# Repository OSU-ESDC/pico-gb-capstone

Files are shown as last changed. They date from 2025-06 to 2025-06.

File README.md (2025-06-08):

# Gaming System - A Modified RP2040 GB for the ENGR 512 Capstone group at Oregon State University

This is a fork of the [RP2040-GB Game Boy (DMG) emulator by YouMakeTech, originally forked from Deltabeard's version](https://github.com/YouMakeTech/Pico-GB). RP2040-GB is a Game Boy (DMG) emulator Peanut-GB on the Raspberry Pi RP2040 microcontroller, using an ILI9225 screen. Runs at more than 70 fps without audio emulation. With frame skip and interlacing, can run at up to 120 fps.

This fork includes changes done by me for my Capstone project in Winter/Spring 2025:
* Volume control via rotary encoder support
* Game movement via analog joystick support
* I2C communication with ADC support, enabling the analog joystick to be used

The Gaming System has a 3D printed shell, designed by Justin Gonzalez. You can find the stl files for the print in the print folder. 

# Videos
* [Analog Joystick Functionality](https://www.youtube.com/shorts/wKSmv8ernYQ)
* [Case Dissasembly](https://www.youtube.com/shorts/b-UEHgNEkO8)
* [Volume Knob Functionality](https://www.youtube.com/shorts/HMfL2WKNLts)

# Hardware
## What you need
* (1x) [Raspberry Pi Pico](https://amzn.to/3rAcmDy)
* (1x) [ADS7830 8-bit, 8-channel, I2C ADC](https://www.adafruit.com/product/5836)
* (1x) [Rotary Encoder](https://eecs.engineering.oregonstate.edu/education/tekbotSuite/tekbot/pages/publicInventoryPart.php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)
* (1x) [Analog Joystick](https://eecs.engineering.oregonstate.edu/education/tekbotSuite/tekbot/pages/publicInventoryPart.php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)
* (1x) [2.2inch ILI9225 176×220 LCD Display Module](https://amzn.to/3aNAMD7)
* (1x) [FAT 32 formatted Micro SD card + adapter](https://amzn.to/3ICKzcm) with roms you legally own. Roms must have the .gb extension and must be copied to the root folder.
* (1x) [MAX98357A amplifier](https://www.youmaketech.com/max98357)
* (1x) [2W 8ohms speaker](https://amzn.to/3ikDy6S)
* (8x) [Micro Push Button Switch, Momentary Tactile Tact Touch, 6x6x6 mm, 4 pins](https://amzn.to/3dyXBsx)
* (1x) [Solderable Breadboard](https://amzn.to/3lwvfDi)
* [Dupont Wires Assorted Kit (Male to Female + Male to Male + Female to Female)](https://amzn.to/3HtbvdO)
* [Preformed Breadboard Jumper Wires](https://amzn.to/3rxwVjM)

## Setting up the hardware
#### Most of the setup is here, minus the analog joystick/rotary encoder:
[Pico-GB assembly instructions, circuit diagrams, 3d printed files etc.](https://www.youmaketech.com/pico-gb-gameboy-emulator-handheld-for-raspberry-pi-pico/)
You can find the rest of the setup in the documentation in the /docs folder.  

# Pinout
* I2C SDA = GP0
* I2C SCL = GP1
* UP = GP2
* DOWN = GP3
* LEFT = GP4
* RIGHT = GP5
* BUTTON A = GP6
* BUTTON B = GP7
* SELECT = GP8
* START = GP9
* VOLUME DT = GP10
* VOLUME CLK = GP11
* SD MISO = GP12
* SD CS = GP13
* SD CSK = GP14
* SD MOSI = GP15
* VOLUME MUTE = GP16
* LCD CS = GP17
* LCD CLK = GP18
* LCD SDI = GP19
* LCD RS = GP20
* LCD RST = GP21
* LCD LED = GP22
* MAX98357A DIN = GP26
* MAX98357A BCLK = GP27
* MAX98357A LRC = GP28

# Flashing the firmware
* Download RP2040_GB.uf2 from the [releases page](https://github.com/osu-esdc/pico-gb-capstone/releases)
* Push and hold the BOOTSEL button on the Pico, then connect to your computer using a micro USB cable. Release BOOTSEL once the drive RPI-RP2 appears on your computer.
* Drag and drop the UF2 file on to the RPI-RP2 drive. The Raspberry Pi Pico will reboot and will now run the emulator.

# Preparing the SD card
The SD card is used to store game roms and save game progress. For this project, you will need a FAT 32 formatted Micro SD card with roms you legally own. Roms must have the .gb extension.

* Insert your SD card in a Windows computer and format it as FAT 32
* Copy your .gb files to the SD card root folder (subfolders are not supported at this time)
* Insert the SD card into the ILI9225 SD card slot using a Micro SD adapter

# Building from source
The [Raspberry Pi Pico SDK](https://github.com/raspberrypi/pico-sdk) is required to build this project. 
To start, clone the SDK in a known folder (labeled as path-to-sdk in future commands), update CMake and submodules, and export the pico sdk path:
```
git clone git@github.com:raspberrypi/pico-sdk.git
cd pico-sdk
git submodule update --init
sudo apt install cmake python3 build-essential gcc-arm-none-eabi libnewlib-arm-none-eabi libstdc++-arm-none-eabi-newlib 
export PICO_SDK_PATH=<path-to-sdk>/pico-sdk
cd ..
```
Clone this repository and create a build folder:
```
git clone git@github.com:osu-esdc/pico-gb-capstone.git
cd pico-gb-capstone
mkdir build
cd build
```

Build a Makefile for the project (no debugging):
```
cmake ..
```

Create the executable and program the Pico:
```
make
sudo openocd -f interface/cmsis-dap.cfg -f target/rp2040.cfg -c "adapter speed 5000" -c "program RP2040_GB.elf verify reset exit"
```

#### For debugging using a Pico Tool (using gdb server and client):
Build a Makefile for the project (with debugging):
```
cmake .. -DCMAKE_BUILD_TYPE=Debug
```
Run the following in one window:
```
sudo openocd -f interface/cmsis-dap.cfg -f target/rp2040.cfg -c "adapter speed 5000"
```
Then run this in the other window:
```
arm-none-eabi-gdb
(gdb) start_pico
```
For tips on setting up debugging tools, follow the [Arm GNU Toolchain setup guide](https://github.com/osu-esdc/Arm-GNU-Toolchain-Setup)

# Known issues and limitations
* No copyrighted games are included with Pico-GB / RP2040-GB. For this project, you will need a FAT 32 formatted Micro SD card with roms you legally own. Roms must have the .gb extension.
* The RP2040-GB emulator is able to run at full speed on the Pico, at the expense of emulation accuracy. Some games may not work as expected or may not work at all. RP2040-GB is still experimental and not all features are guaranteed to work.
* RP2040-GB is only compatible with [original Game Boy DMG games](https://en.wikipedia.org/wiki/List_of_Game_Boy_games) (not compatible with Game Boy Color or Game Boy Advance games)
* Repeatedly flashing your Pico will eventually wear out the flash memory (Pico is qualified for min. 100K flash/erase cycles)
* The emulator overclocks the Pico in order to get the emulator working fast enough. Overclocking can reduce the Pico’s lifespan.
* Use this software and instructions at your own risk! I will not be responsible in any way for any damage to your Pico and/or connected peripherals caused by using this software. I also do not take responsibility in any way when damage is caused to the Pico or display due to incorrect wiring or voltages.

# License
MIT

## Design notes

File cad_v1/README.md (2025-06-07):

# This folder contains the files for the Gaming System Shell, version 1 (the one presented at the S2025 Expo with no PCB). 

### There are two folders for the CAD files - one for STEP files, and one for STL files. 
- Use the STL files to print the controller shell.
- Use the STEP files to open the controller shell design and make edits to it.

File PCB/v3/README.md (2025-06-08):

### This folder contains all the folders and files necessary to edit and manufacture the Gaming System's PCB.
#### Folders: 
- The gerber files folder contains all of the gerber files required to get the PCB manufactured. You can ignore the "Capstone_1-bottom" and "Capstone_1-top" files.
- The myLibrary.pretty folder contains additional footprints for the PCB.

#### Files (within this directory): 
- There are 3 important files in this directory:  
        capstone_3.kicad_pro - project file to edit files  
        capstone_3.kicad_pcb - board layout file  
        capstone_3.kicad_sch - schematic file

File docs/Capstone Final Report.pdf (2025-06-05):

# Gaming System

# Final Report

### Gabriel Rodgers Jaedo Oh Mitchell Hopkins Justin Gonzalez Atom Rousseau

2025

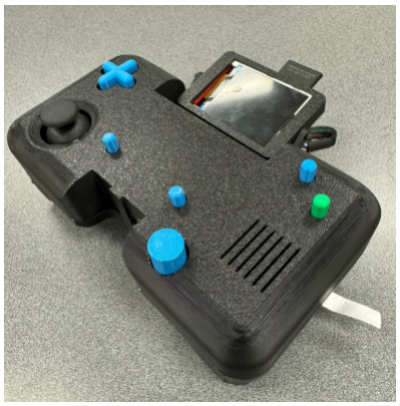
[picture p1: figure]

Project Sponsor: Embedded Systems Design Club Faculty Advisor: Dr. Renato Figueiredo Instructor: Christopher Holm

## DISCLAIMER

This report was prepared by students as part of a university course requirement. While considerable effort has been put into the project, it is not the work of licensed engineers and has not undergone the extensive verification that is common in the profession. The information, data, conclusions, and content of this report should not be relied on or utilized without thorough, independent testing and verification. University faculty members may have been associated with this project as advisors, sponsors, or course instructors, but as such they are not responsible for the accuracy of results or conclusions.

ENGR 512 Gaming Console
Gonzalez, Hopkins, Oh, Rodgers, Rousseau

## ABSTRACT

The Gaming System is a portable handheld console designed to emulate original Nintendo Gameboy games while integrating modern enhancements. Built around the Raspberry Pi Pico microcontroller, the system uses the open-source Pico-GB Gameboy emulator [1] as its software backbone. Additional features such as a variable volume knob and analog joystick input expand the functionality beyond the original Gameboy interface, offering a more modern and user-friendly interface. The hardware consists of 3 custom-designed printed circuit boards (PCBs), which support a modular electronics layout. This modularity simplifies assembly, maintenance, and potentially future upgrades. The PCBs integrate the microcontroller, input/output components, and power management systems. The physical enclosure is a custom 3D-printed housing with an articulating screen, 8 tactile buttons, a power switch, 2 AA removal batteries, an analog stick, a volume knob, an audio amplifier, a speaker, and a removable top shell for ease of access. Ergonomics and portability were key design drivers, ensuring the device fits comfortably in the user’s hands while remaining compact enough for easy travel. The final product met all 10 of our engineering specifications (refer to Appendix A-House of Quality). It delivers 50 minutes of continuous gameplay on 2 AA batteries and maintains seamless emulation performance across various different games. The joystick provides a versatile input option for future game compatibility, while the volume knob enables fine-tuned audio control. The Gaming System successfully combines retro gaming with modern usability, resulting in a robust and modular handheld device.

## ACKNOWLEDGEMENTS

We would like to thank the Embedded Systems Design Club for sponsoring our project and providing valuable resources and support throughout the development. We are especially grateful to Sami Aljabery and Dr. Renato Figueiredo for their guidance on refining the software scope and ensuring feasibility within our timeline. We also extend our sincere thanks to Dr. John Greeven and Christopher Holm for their continuous advising on PCB design, hardware implementation, and the overall project direction, as well as for their support throughout the Capstone course.

## TABLE OF CONTENTS

## Contents

DISCLAIMER | 1
ABSTRACT | 2
ACKNOWLEDGEMENTS | 3
TABLE OF CONTENTS | 4
1 BACKGROUND | 2
1.1 Introduction | 2
1.2 Project Scope | 2
2 DESIGN PROCESS | 5
2.1 General Process | 5
2.1.1 PCB Design Process | 5
2.1.2 Shell Design Process | 5
2.1.3 Software Design Process | 6
3 DESIGN PROPOSAL – First Term | 7
3.1 Shell Design | 7
3.2 PCB Original Design | 7
3.3 Software Original Design | 7
4 Design Solution | 8
4.1 Description of Solution | 8
4.2 Project Results | 9
5 LOOKING FORWARD | 11
5.1 Software Future Updates | 11
5.2 PCB Future Updates | 11
5.3 Shell Design Updates | 11
6 CONCLUSIONS | 12
7 REFERENCES | 13
8 APPENDICES | 14
8.1 Appendix A: House of Quality | 14
8.2 Appendix B: Bill of Materials | 15
8.3 Appendix C: Hinge Drawing | 16

## 1 BACKGROUND

### 1.1 Introduction

The Gaming System Capstone project aims to develop a modern, handheld gaming system capable of playing the original Nintendo Gameboy games while enhancing the functionality through contemporary hardware features. The interdisciplinary team was composed of 2 Electrical and Computer Engineering (ECE) students and 3 Mechanical, Industrial, and Manufacturing Engineering (MIME) students, who collaborated to integrate a custom PCB, an ergonomic industrial design, and a modified open-source emulation software into a cohesive product. The primary objectives of this project are to create a modular, ergonomic, and user-friendly device that replicates the nostalgic Gameboy experience while introducing modern controls such as an analog joystick. These improvements reflect modern user expectations and broaden the system’s potential applications in education, prototyping, and entertainment. This project is important because it addresses contemporary issues in sustainable product development, hardware modularity, and cross disciplinary design. In a new era where electronic waste and planned obsolescence are growing concerns, the Gaming System promotes longevity through its repairable design and replaceable power source. The use of the open-source software and custom PCBs encourages low-cost development and potential scalability. For the project sponsor and stakeholders, including engineering faculty and future capstone teams, this gaming system serves as a demonstrator of what is achievable through coordinated multidisciplinary collaboration. It provides a foundation for further innovation in embedded systems, custom electronics, and human centered product design. This Gaming System delivers not just a product, but a platform for continued learning and development.

### 1.2 Project Scope

The Gaming System is a fully functional gaming system capable of playing original Gameboy games. The purpose of the Gaming System Capstone project is to provide a valuable learning experience for the project’s team members. This value comes from the experience of collaborating with a team of interdisciplinary engineers and the technical expertise acquired by building the Gaming System from scratch. To gain this expertise, the Capstone team members have added features to the original Gameboy system (and implemented a new PCB/physical design). For background, the original Gameboy came with a volume knob but no analog joystick. It was released in 1989 and has been one of the most iconic gaming systems ever created [2]. Existing Gameboy emulator systems (such as Pico-GB) do not support all original Gameboy features (such as a volume knob) and do not add more features to the original Gameboy system (such as an analog joystick). The Gaming System capstone project aims to add a volume knob and an analog joystick to the Pico-GB project (this includes writing software and integrating these two pieces of hardware onto the PCB). Lastly, the Gaming System aims to create a comfortable physical design (and custom PCB) that is significantly different from any previous 3rd party Gameboy systems [3]. See Figure 1 for an example of a 3rd party Gameboy system.

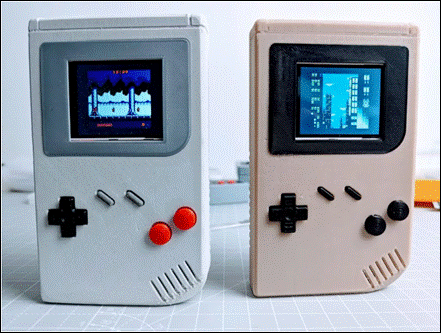
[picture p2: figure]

Figure 1. A 3

rd party Gameboy system’s physical design, by Vincent Mistler [3].

The Gaming System has three main design components. The first is the physical design; the three MIME members (Atom Rosseau, Justin Gonzalez, and Jaedo Oh) have created their own designs for a novel, 3D-printed controller. The Gaming System controller shell can be 3D printed by standard Fused Deposition Modeling (FDM) printers which use plastics such as Polylactic Acid (PLA) at high temps to replicate 3D objects. This makes the project easily accessible to anyone with an interest in the project, by having open-sourced files for those as well as the printed circuit boards (PCB) to match.The second is the PCB of the system, created by one of the ECE members (Mitchell Hopkins). The PCB contains (and connect) the following components, most of which were sourced from external manufacturers:
- 1 Raspberry Pi Pico development board (which consists of a PCB and an RP2040 microcontroller chip)
- 1 audio amplifier breakout board
- 1 analog to digital converter (ADC) breakout board
- 1 analog joystick breakout board
- 1 rotary encoder
- 8 push buttons
- 1 switch
- 1 LCD screen
- 1 speaker
- 2 AA batteries
The third is the software, which was written by the other ECE member (Gabriel Rodgers). The bulk of the software is provided by the open-source Pico-GB project [1], a Gameboy emulator that works for Raspberry Pi Pico development boards. Gabriel Rodgers has added functionality to the Pico-GB project to support an analog joystick and a rotary encoder by writing additional software for the Pico-GB project. Users can control Gameboy games on the Gaming System by using the analog joystick in the same manner as the push buttons. Users can change the volume of the Gaming System by rotating the rotary encoder. The Gaming System as presented during the Engineering Expo is based on a protoboard electronic system (i.e., one that is wired without a PCB). This is because the PCB was not manufactured in time for it to be integrated into a new controller shell design.

## 2 DESIGN PROCESS

### 2.1 General Process

Our team began by collecting customer requirements to formulate what needed to be included in the creation of the gaming system. This process was carried out by the team, with the Embedded Systems Club serving as our sponsor and primary contributor to the project. This has led to our requirements to be well-defined, which helps with the overall design process. Our requirements are to be portable, have a standard layout of buttons and a directional pad, have a flexible hinge for the screen, and have easy access to the internals of the system. Our goal is to have this project be cost-effective and easy to assemble. Since the project will be using a Raspberry Pi Pico, the system will be power efficient, and we will be powering the whole system with AA batteries.

### 2.1.1 PCB Design Process

The original idea was just using one PCB and connecting everything directly on that PCB. With the change in outer shell design, the single PCB design was not sufficient. There are more moving parts, so the team decided to break up the PCB into three separate parts. The largest PCB was placed in the center and it is the main one with the microcontroller and the other PCBs connected to it and that will be where the power is connected. The other two PCBs will be for buttons, one is the classic video game d-pad used to move in four directions and the other is the symbol buttons classically used to advance the story of the game and perform functions that are not related to movement. The d-pad is implemented with the possibility of it becoming a joystick instead, which allows for more directional movement that is not just up, down, left or right.

### 2.1.2 Shell Design Process

Through different prototyping phases as well as different brainstorming ideas we developed a few ideas that would help us determine the direction that we would want to take in the future. The designs and ideas for those designs through our early brainstorming phase is shown below.

Brainstorm | Prototype

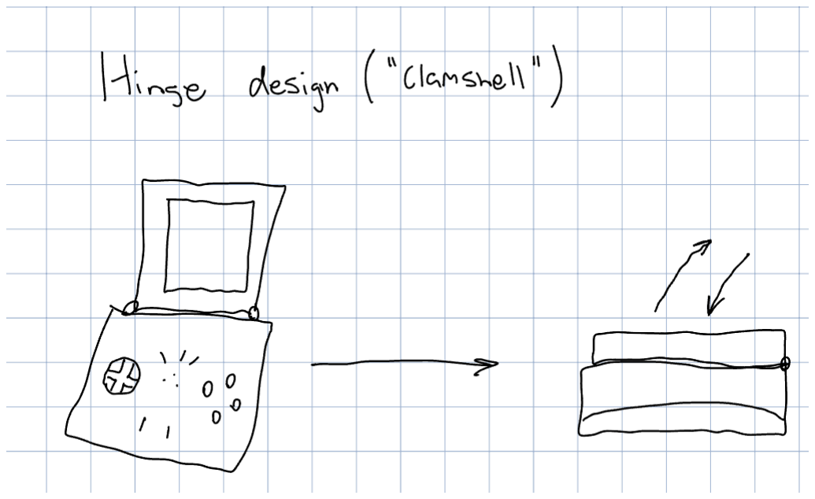
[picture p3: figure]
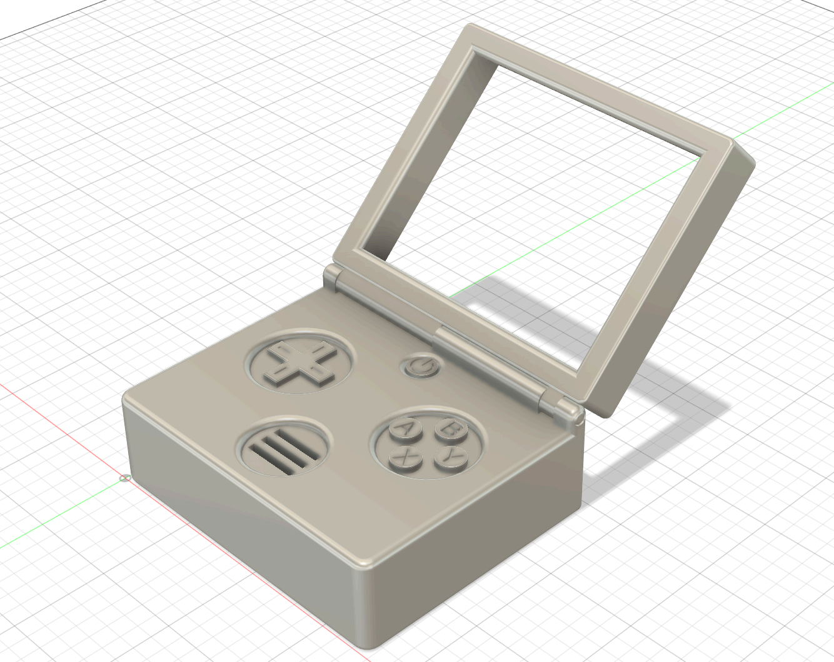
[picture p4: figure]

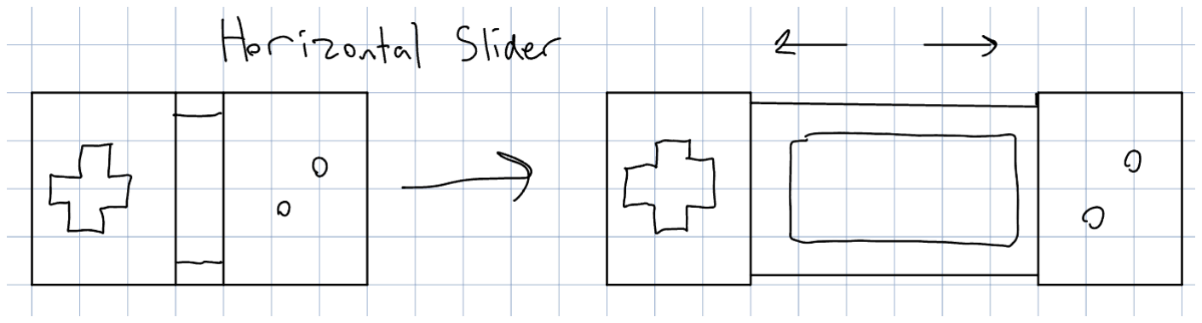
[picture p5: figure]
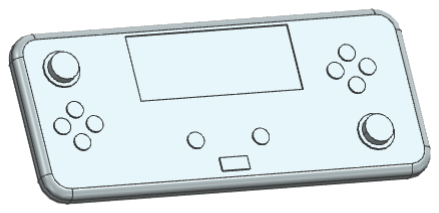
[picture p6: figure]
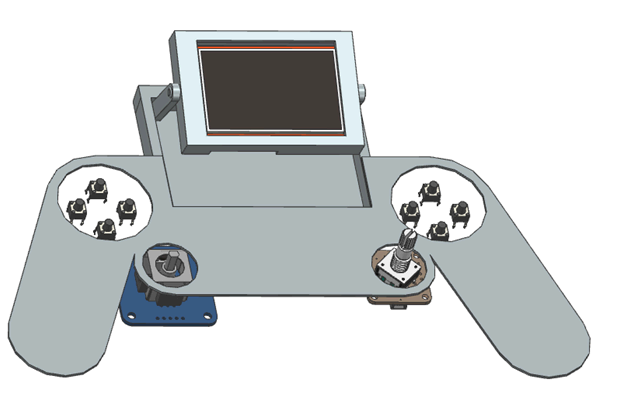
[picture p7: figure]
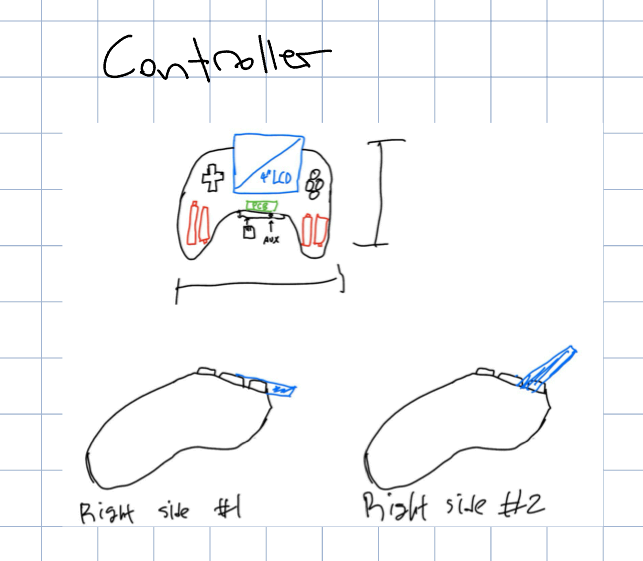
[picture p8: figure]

Figure 2. Brainstormed ideas and their resulting prototype.

These prototypes were created based on our brainstormed ideas. The idea was to see physically if we preferred a type of direction from our brainstorming session and having a physical representation of the shape and feel would give us the best idea of what we could work around. Ultimately we ended up going in the direction of the last design where the shape and feel would be based more like a controller. This was because of its potential for better ergonomics and ability to be flexible when it comes to what parts we could add and where we would be able to put them.

### 2.1.3 Software Design Process

The software design process involved redefining the scope of the software (from writing code to manipulate registers to writing code that uses Pico Software Development Kit (SDK) function calls), figuring out how to implement functionalities, and testing. Because the Gaming System uses the Pico-GB emulator software as its base, the added functionality needed to be quick and to not impede the activities of the emulator. To do this, we pondered the use of Direct Memory Access (DMA) to move joystick data from the analog to digital converter (ADC) to the Pico without interrupting the emulator. Before implementing DMA functionality, however, we first wrote software to test whether non-DMA software would work fast enough to be unnoticeable from the existing emulator. We found that there was no need for a DMA version of the software as the emulator was not significantly slowed down by the added software. As for the rotary encoder, it was trivial to use the Pico SDK function calls and an interrupt to determine if the rotary encoder was being moved - and to correspondingly change the Gaming System’s volume.

## 3 DESIGN PROPOSAL – First Term

### 3.1 Shell Design

The design for the shell shifted a lot from the previous term as nothing was set in stone as the only thing that had been created with any physicality to it was the hinge (refer to Appendix C-Hinge Drawing). This served to not only act as a proof of concept but to help guide some of the size requirements for later. Doing the proofs of concepts in the first term solidified the direction that we wanted to take the gaming console. This is helpful as we would need to spend a lot of time prototyping different shapes and designs. Instead we just did it for the few designs that we had in mind. The proof of concepts also allowed us to build the resulting shape around our main mechanism being the hinge. Since the hinge takes up a lot of space this defines the shape that would eventually become the shell.

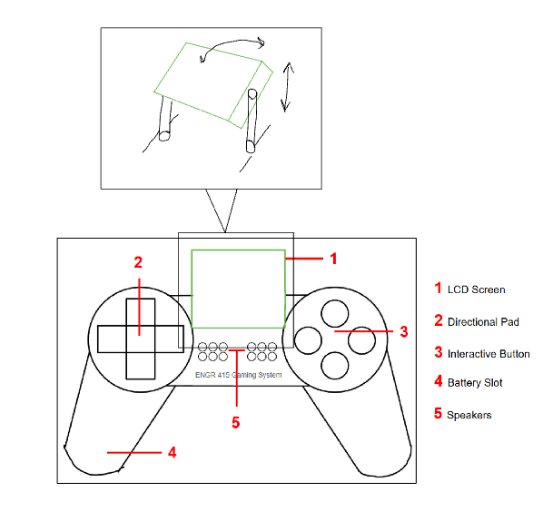
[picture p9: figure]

Figure 3. Original Proof of concept from first term

This is the basis of the shape that we decided on last term. As you can see the shape was built around the screen being able to move so the rest of the shape forms around the main mechanism. The idea for more of a controller shape is the largest thing that changed from the first term. This was due to the amount of space that was needed to house the electronics; the shape of the shell would be too large to incorporate the electronics while also remaining in a controller shape. As the prototype uses a protoboard the amount of space needed was a lot more than originally thought which led to the overall size of the shell being much larger than originally thought in the first term. The original thought, which is the prototype in the section above and the last figure in figure 2 was to keep the controller type shape while still being able to incorporate all of the electronics.

### 3.2 PCB Original Design

The original design was a single PCB that had all components soldered on the board. The only exception is that the LCD screen was on its own and connected to the board via wires. The design also had to work with curved areas and when connecting the line etches, they need to be lines and not curves. With the shell design not being fully integrated, the lab design was changed to be less rigid since the time to and money to change the PCB is much greater than that of the shell. The new design breaks up all of the original design into three separated PCBs that are connected directly to the main PCB. Also connected to the main PCB are all of the non button components to make it easier to move the components and make them fit in a way that is more comfortable for the user, which is our main goal.

### 3.3 Software Original Design

The original design for the software did not change from the first term to the second term.

## 4 Design Solution

This section outlines the final design implemented by our team for the Gaming System project. The mechanical and user interface components were developed with a focus on portability, ergonomics, and functionality, while ensuring ease of manufacturing and reproducibility for future users and developers. The system’s final form reflects a balance between design simplicity and comprehensive input and display features.
The following subsections detail the physical design of the solution and the results from testing the system against the defined engineering specifications.

### 4.1 Description of Solution

The final implementation of our gaming system is a compact, handheld console designed with portability, usability, and modularity in mind. The outer housing was fabricated using 3D printing technology, utilizing PLA filament due to its accessibility, ease of printing, and sufficient mechanical properties for handheld device enclosure. The shell was designed with curvature to improve hand grip comfort and reduce fatigue during extended gameplay sessions.
The system features a 2.2 inch color LCD display, which is mounted on an articulating hinge structure. This hinge enables users to tilt the screen to their preferred viewing angle, improving visibility and usability in various lighting conditions and hand positions. The hinge was designed to maintain positional stability while allowing smooth adjustments, inspired by devices such as the Nintendo DS (figure 4).

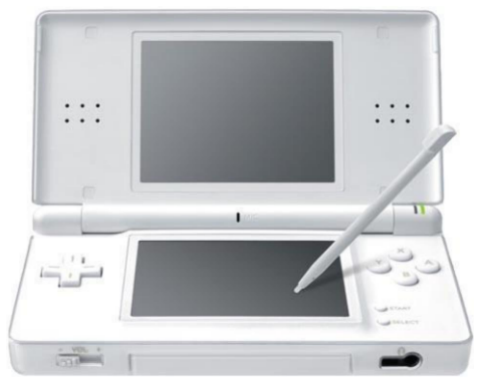
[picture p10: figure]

Figure 4. The Nintendo DS, a dual-screen handheld gaming console, features a clamshell design with a central hinge allowing the top screen to be tilted for optimal viewing. This mechanism inspired the adjustable LCD screen hinge implemented in our Gaming System. The user interface consists of a total of seven input controls: a directional D-pad, an analog joystick, two action buttons (A and B), Start and Select buttons, and a rotary volume knob. The joystick was added in addition to the D-pad to improve enhanced directional input and support for games or creatures that may benefit from analog movement. All buttons were chosen for their tactile response and were embedded securely into the front face of the housing.
Figure 5 shows the completed physical assembly of the Gaming System. The device’s black PLA enclosure is contrasted with colored buttons for clear visual identification of input functions. The joystick is positioned for left-thumb use, while the D-pad is placed above it. The rotary knob, located in the lower left, provides analog volume control. The LED screen is seen mounted on a hinged section in the upper center of the device, enabling flexible screen positioning.
Power is supplied through two replaceable AA batteries, housed in a rear-mounted battery compartment. This design choice allows for convenient battery replacement without requiring tools. Based on empirical testing, the system can operate continuously for approximately 50 minutes under typical load conditions, which include active gameplay with screen brightness and audio at medium levels. Because the PCB was not manufactured in time for the Engineering Expo, we instead created a protoboard prototype of the system, soldering all of the components together on a protoboard and placing it within the custom shell design.
The software for the Gaming System is based on the Pico-GB emulator, with an additional ~hundred lines of C code to support volume control via a rotary encoder and game movements via an analog joystick and ADC. The added software includes Pico SDK function calls to operate the I2C (inter-integrated circuit) peripheral for the ADC, read the values of the GPIO pins connected to the rotary encoder, and to create interrupts to determine which way the rotary encoder is turnt. This added software does not impact the emulator’s ability to run more than 5 original Gameboy games at low latency (more than 1 frame per second), which satisfies two of the engineering requirements.
In summary, the final design balances mechanical simplicity with user-oriented features, emphasizing ergonomic handling, screen adjustability, accessible power, and robust input methods, all packaged in a fully 3D-printed housing optimized for cost-effective assembly.

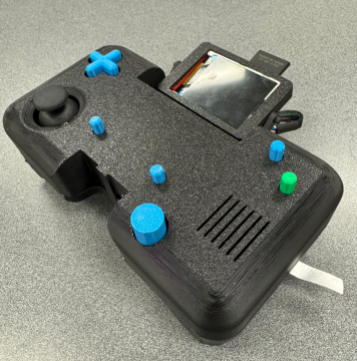
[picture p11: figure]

Figure 5. Assembled Gaming System showcasing LCD screen, joystick, buttons, and 3D-printed housing.

### 4.2 Project Results

To validate the design, the Gaming System was tested against the full set of engineering specifications established during the first term. These specifications focused on functionality, ergonomics, battery life, display usability and control responsiveness [4]. The system showed stable performance during gameplay, with all inputs registering correctly and without noticeable input lag. The D-pad and joystick were tested for responsiveness and accuracy in games that required both rapid button inputs and directional control. The volume knob demonstrated variable resistance control, smoothly adjusting the audio output without artifacts or noise glitches. Battery tests were conducted under typical use conditions - standard brightness, default speaker volume, and active gameplay. Under these settings, the system sustained operation for approximately 50 minutes using two AA batteries, meeting the target duration. The battery compartment design enabled seamless replacement, and the system rebooted correctly upon reinsertion of new batteries. Additionally, the articulating hinge mechanism for the LCD scream was tested across multiple tilt angles. It maintained its position during gameplay and did not show signs of mechanical fatigue or slippage after repeated adjustments. The shell also easily survived a drop onto concrete from a height of 1 meter, satisfying its associated engineering specification.All engineering specifications were tested and the Gaming System passed them all without issue.
Overall, the system was presented to the instructor, who validated the intended usability and design principles. All hardware components functioned as expected, and no critical failures occurred during extended demonstrations. Various members from ESDC tested the Gaming System for comfort, functionality, and usability. All were impressed with the system, with some stating how comfortable it was to use the analog joystick.

## 5 LOOKING FORWARD

### 5.1 Software Future Updates

Our future goal for the software is to modify it to be more modular, readable, and maintainable. The modularity would be used to allow for users to modify the source code to support Gaming Systems that have different combinations of analog joysticks/rotary encoders. The other two would be helpful for future Capstone projects that want to use a similar emulator. After updating the codebase, we would ideally merge our project with the original Pico-GB emulator, which would be a significant contribution towards open-source software.
For any future Capstone teams attempting something similar/continuing with this project, we would recommend trying to add additional functionality to an original Gameboy emulator, refactoring the existing emulator for performance, refactoring our code for performance (by using DMA for communications between the Pico and the ADC) [5], porting the emulator to a newer Pico model (such as the Pico 2), or using a more advanced emulator (such as for the Nintendo DS or Nintendo NES). One thing to be aware of is that when writing software, try the easiest solution first just to see if the functionality is even functional. One can always make the solution more efficient from there.

### 5.2 PCB Future Updates

In the future all three boards will be implemented into one because it will be easier to manufacture, but the current design is meant to be flexible and that makes it easier to fit in the outer shell. With the next iteration of the PCB, the wiring of the buttons will need to be re-worked because with the connection between boards the orientation of the buttons was flipped to avoid etched lines crossing. The etched lines on the PCB going to the encoder will need to be reorganized because when the encoder gets soldered into the board, the current connections will be wired incorrectly. Lastly, the connections between the boards used GH JST connectors that are 1.27mm apart, however, the actual components have differing widths, so using the standardized 1.27mm width between pins will make it so the components will not be able to be inserted into the board. The width of the holes between pins for the buttons and the microcontroller are correct.

### 5.3 Shell Design Updates

Looking ahead, we aim to significantly reduce the overall thickness and weight of the Gaming System shell to improve portability and ergonomics. With a planned integration of all electronic components onto a single custom PCB, we will have greater freedom to redesign the internal layout and optimize the form factory. A thinner shell will enhance the handheld feel of the device and make it more comfortable for extended gameplay sessions. The redesign will also address internal space constraints, allowing better alignment between the component and mounting features. We also plan to improve accessibility to internal components such as the batteries and the joystick.

## 6 CONCLUSIONS

The main goal of the Gaming System Capstone project was to create a valuable learning experience by collaboratively designing and integrating software, hardware, and a physical shell together. Through this project, the team successfully applied engineering including user-centered design, modularity, and manufacturability. By building a custom device from the ground up, the team gained heads-on experience in embedded systems, 3D design, open source firmware development, and rapid prototyping.
The Gaming System fulfilled all of its intended functional requirements. It was able to play original Gameboy ROMs using the Pico-GB emulator while incorporating new user features such as an analog joystick and rotary volume control. These additions enhanced the functionality beyond that of the original Gameboy system and reflected modern usability standards. The hinge-mounted LCD screen provided customizable viewing angles and improved ergonomics, and the use of replaceable AA batteries ensured that the device remained cost-effective and portable.
The Gaming System bridges nostalgia and modern usability, offering a new take on retro gaming. Educationally, it demonstrated the importance of interdisciplinary collaboration. Bringing together electrical engineering, mechanical engineering , software development, and systems integration.
In conclusion, the Gaming System stands as a testament to practical engineering application and cross-functional teamwork. The project not only delivered a working prototype that exceeded technical expectations, but also provided a foundation for future student teams or hobbyists interested in building and expanding upon the system.

## 7 REFERENCES

[1] Mistler, V., 2022, “YouMakeTech/Pico-GB: Game boy emulation on the raspberry pi RP2040 microcontroller.,” GitHub [Online], from https://github.com/YouMakeTech/Pico-GB
[2] “Game boy | National Museum of American History,” National Museum of American History
[Online], from https://americanhistory.si.edu/collections/object/nmah_1253117
[3] Mistler, V., 2022, “Pico-GB GameBoy Emulator Handheld for Raspberry Pi Pico,” YouMakeTech [Online], from
https://www.youmaketech.com/pico-gb-gameboyemulator-handheld-for-raspberry-pi-pico/
[4] Kim, J., and Lee, S., 2021, “The Ergonomic Development of Video Game Controllers,” Longdom Publications, [Online]. from https://www.longdom.org/open-access/the-ergonomic-development-of-video-game-controllers-24 556.html. (https://www.longdom.org/open-access/the-ergonomic-development-of-video-game-controllers-24556.html)
[5] osu-esdc., 2025, “osu-esdc/pico-gb-capstone: Fork of the original Pico-GB git repository, with added volume rocker and analog stick functionality.,” GitHub [Online], from https://github.com/osu-esdc/pico-gb-capstone

## 8 APPENDICES

### 8.1 Appendix A: House of Quality

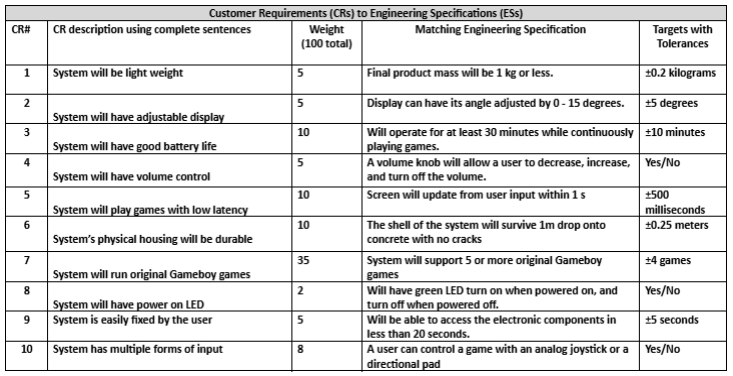
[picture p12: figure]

### 8.2 Appendix B: Bill of Materials

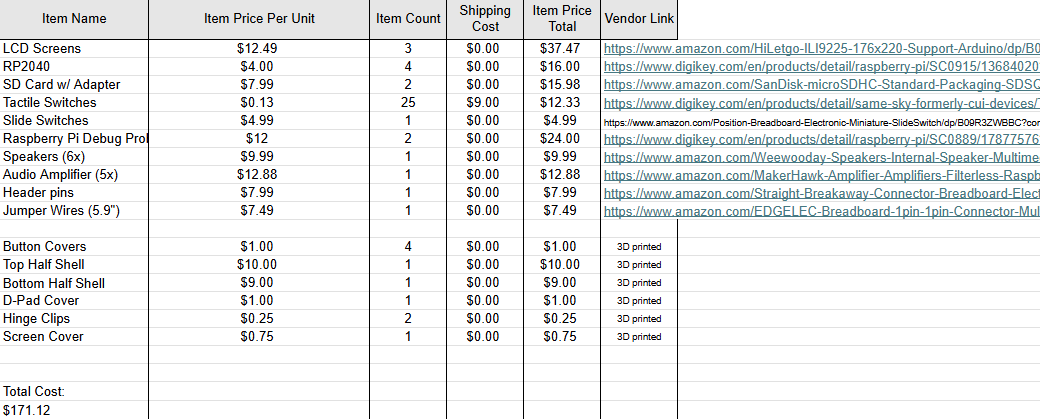
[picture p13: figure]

### 8.3 Appendix C: Hinge Drawing

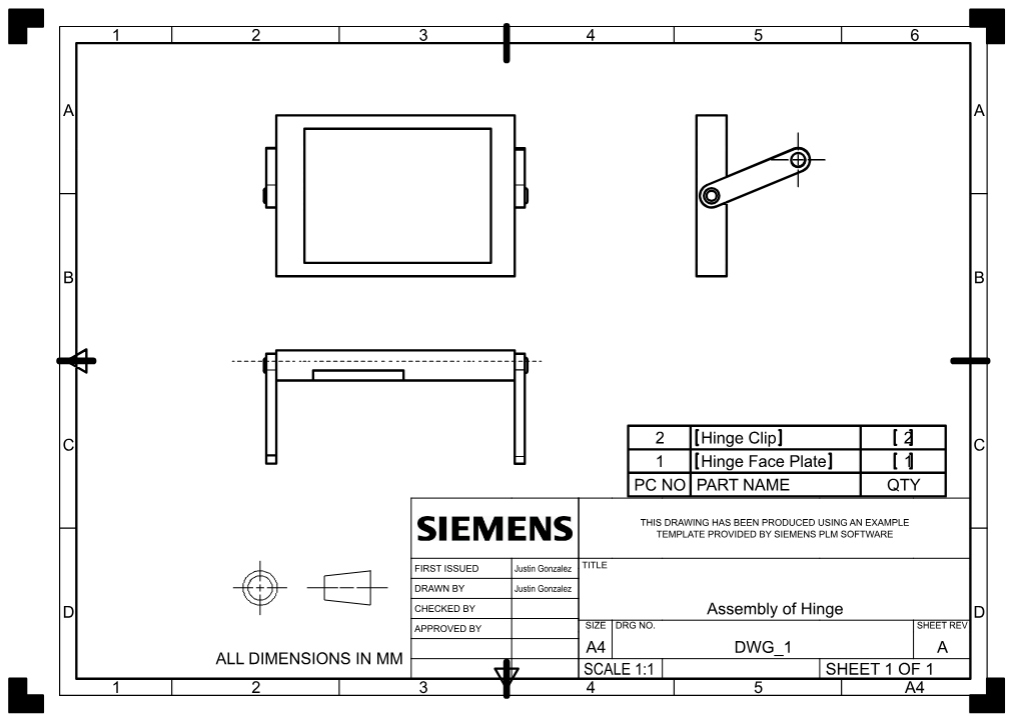
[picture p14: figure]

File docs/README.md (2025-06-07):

### Documentation

#### Files:
* Capstone Electronics Block Diagram.drawio - A drawio file (download then open in draw.io) containing all the blocks and labeled pins in the Capstone Gaming System.  
* Capstone Final Report.pdf -  A pdf file that contains the final report for the Gaming System Capstone project.   
* Capstone Software Guide.pdf - A pdf file that contains a guide to all added software completed in the Capstone Gaming System. Does not cover the original Pico-GB emulator's software.

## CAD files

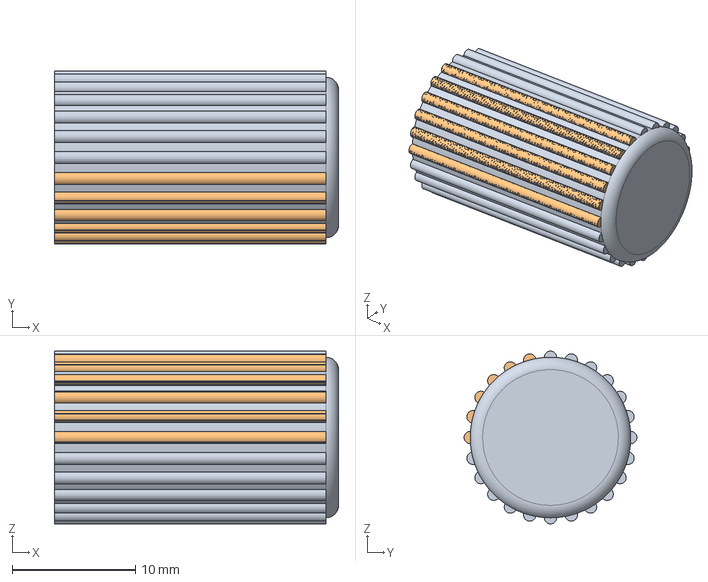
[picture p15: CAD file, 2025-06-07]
cad_v1/step/potcap.stp
23.0 x 14.0 x 14.0 mm

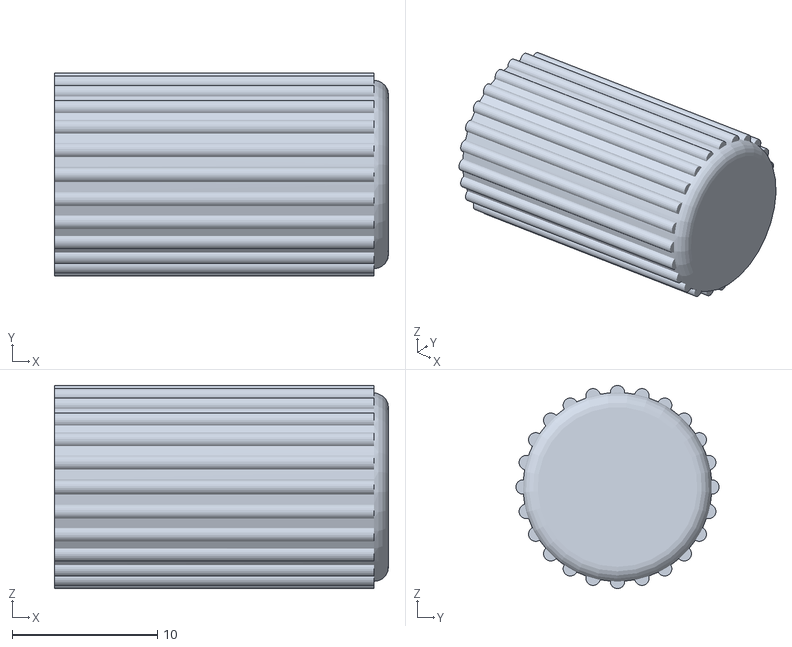
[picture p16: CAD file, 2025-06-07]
cad_v1/stl/potcap_4.stl
23.0 x 14.0 x 14.0

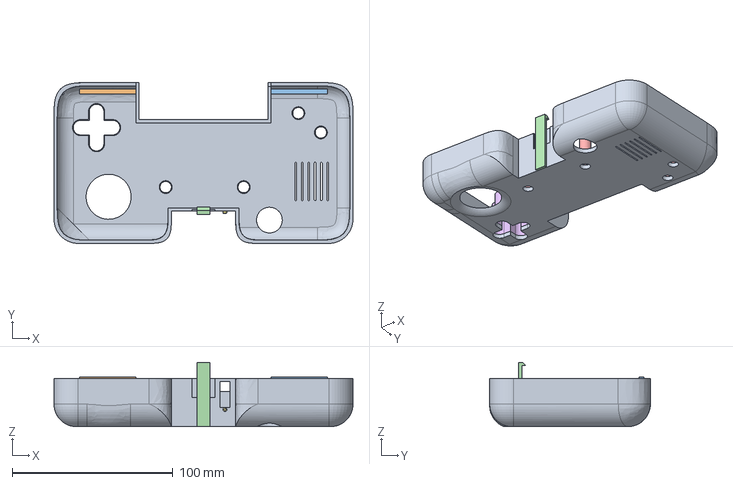
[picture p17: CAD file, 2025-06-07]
cad_v1/step/topcase12.stp
185.9 x 100.0 x 40.0 mm

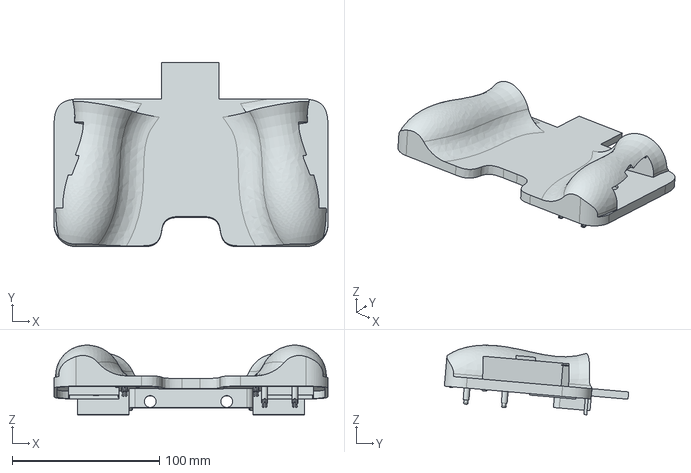
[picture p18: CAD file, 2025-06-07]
cad_v1/step/Bottom_shell.stp
185.9 x 125.1 x 47.3 mm

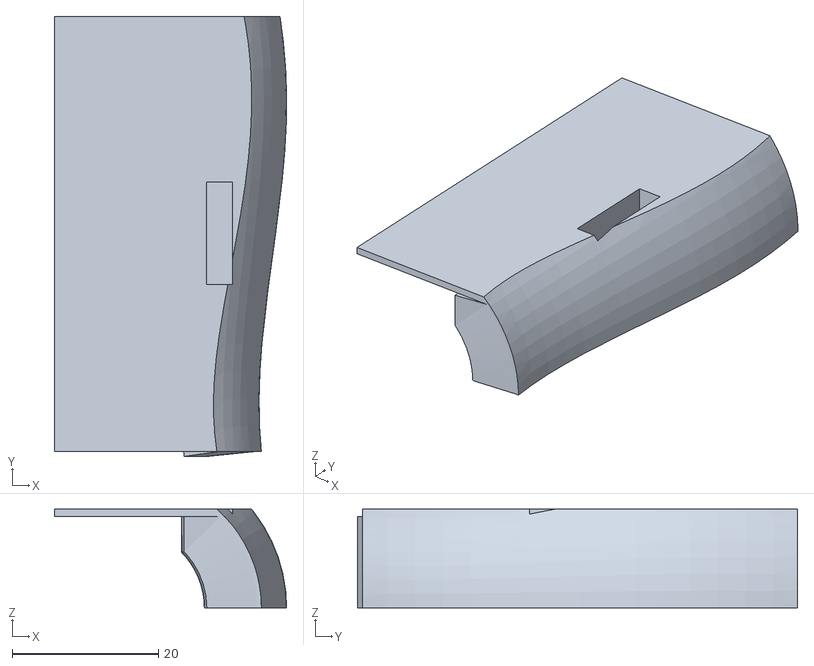
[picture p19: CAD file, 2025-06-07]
cad_v1/stl/Battery_covers.stl
31.8 x 60.2 x 13.5

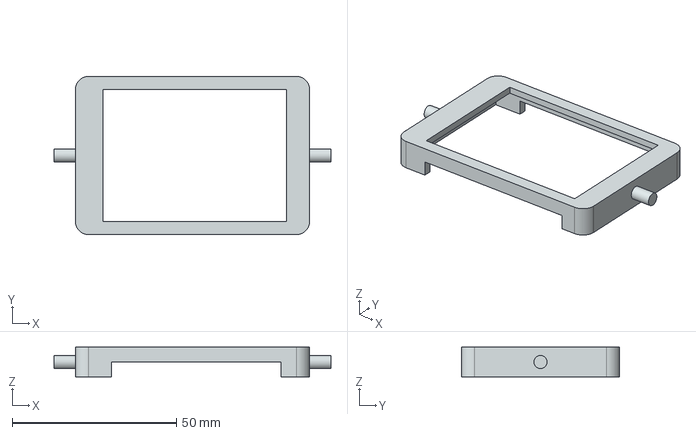
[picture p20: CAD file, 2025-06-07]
cad_v1/step/Screen cover.stp
84.2 x 48.1 x 9.00 mm

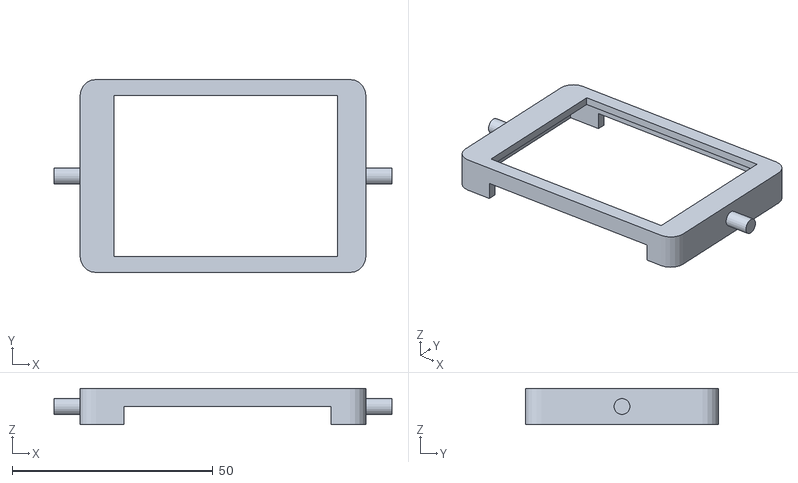
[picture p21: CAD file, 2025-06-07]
cad_v1/stl/Screen cover_4.stl
84.2 x 48.1 x 9.00

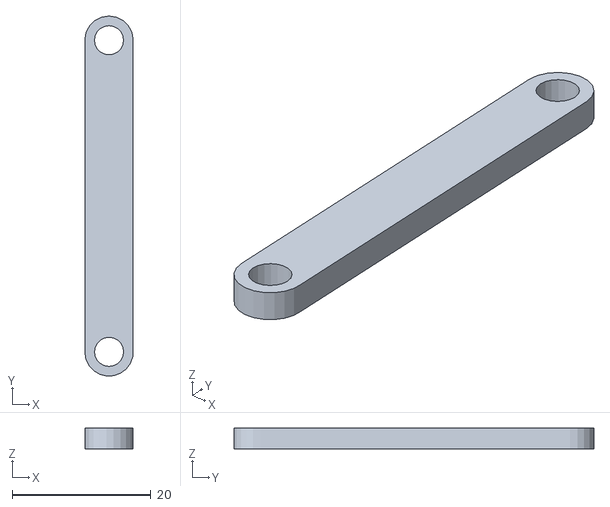
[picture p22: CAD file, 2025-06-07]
cad_v1/stl/hingeclip_4.stl
7.00 x 52.0 x 3.00

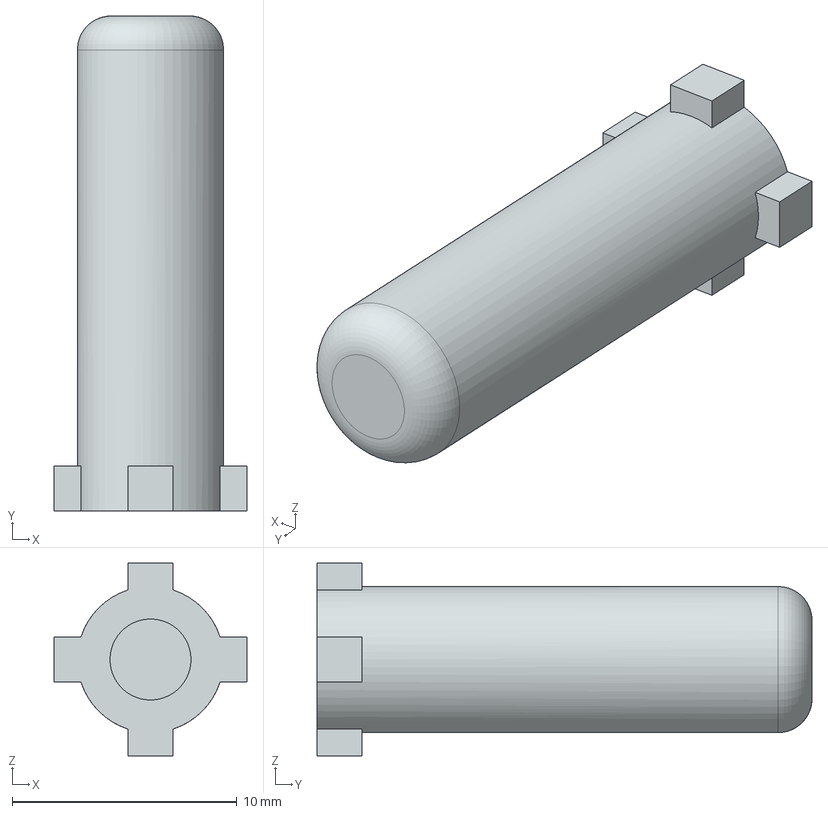
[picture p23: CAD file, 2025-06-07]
cad_v1/step/button_cap.stp
8.56 x 22.0 x 8.56 mm

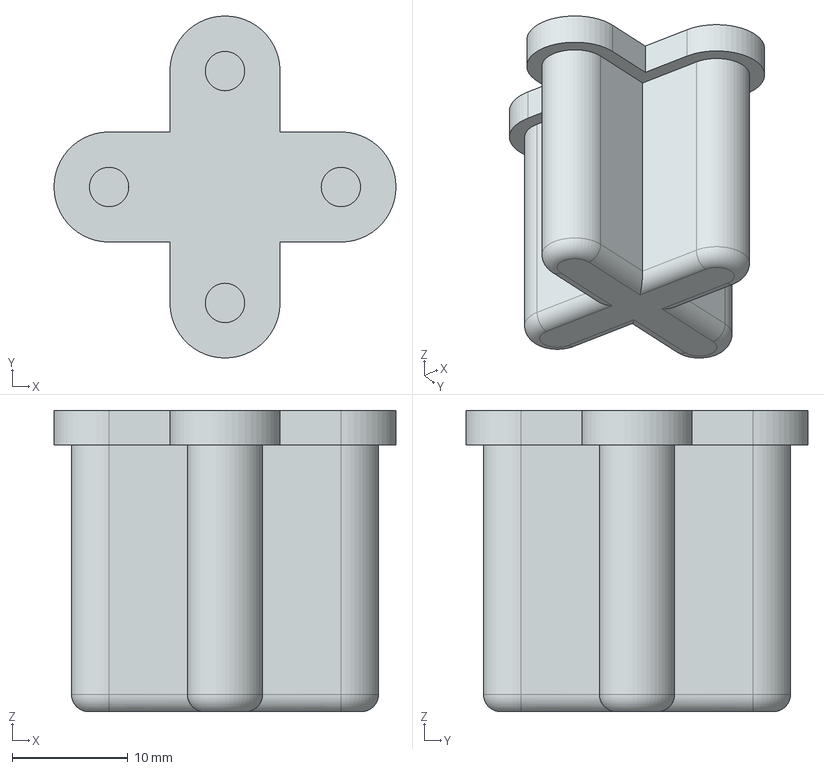
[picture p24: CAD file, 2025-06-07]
cad_v1/step/D_pad.stp
29.5 x 29.5 x 26.0 mm

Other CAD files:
cad_v1/stl/topcase12_18.stl
cad_v1/step/Batterycover.stp
cad_v1/step/hingeclip.stp
cad_v1/stl/Bottom_shell.stl
cad_v1/stl/D_pad.stl
cad_v1/stl/button_cap.stl

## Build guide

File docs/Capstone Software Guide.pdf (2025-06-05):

# Gaming System Software Guide

Author: Gabriel Rodgers
Sponsoring Club: Embedded Systems Design Club
Date: 6/5/2025

Miscellaneous Information
- If you want to add more header files (i.e., like #include <hardware/dma.h>), then you need to add the file name (hardware_dma for the previous example) to the target_link_libraries variable in the CMakeLists.txt file.
- The added code for this project is additional to the Pico-GB project and uses mostly Pico SDK function calls to complete rotary encoder/ADC communications.
- Capstone Members: Gabriel Rodgers, Justin Gonzalez, Jaedo Oh, Mitchell Hopkins, Atom Rousseau
- This Capstone project was completed for Winter/Spring terms of 2024-2025 for the Interdisciplinary Capstone Courses, ENGR415 & ENGR416.
- Capstone project ID: ENGR.512

Volume Control Implementation
- Used 2 GPIO pins (10 and 11) to connect to the rotary encoder’s DT (GP10) and CLK (GP11) pins.
- Used an interrupt on GP10 for rising and falling edges to detect a rotation.
- I also use GPIO pin 16 to connect to the rotary encoder’s switch pin (for muting), though I did not yet implement mute functionality. A user can mute the volume by scrolling counterclockwise for at least 15 dentents.

Rotary encoder variables:
/* Volatile globals */
volatile uint8_t g_volume = 0; volatile uint8_t g_mute = 0;

typedef enum{
VOLUME_INCREASE,
VOLUME_DECREASE,
VOLUME_STABLE
}volume_state_t;
- The volume_state_t typedef enumeration is used to determine what state the volume is in (should it be increased, decreased, or remain the same?). The g_volume global variable is set to one of the volume_state_t values, depending on what the volume should do.

Interrupt logic:
void gpio_vol_scroll(uint gpio, uint32_t event_mask) {
uint8_t clk = gpio_get(GPIO_VOL_CLK);
uint8_t dt = gpio_get(GPIO_VOL_DT);

if (dt == clk) { //cw
g_volume = VOLUME_INCREASE;
}
else { //ccw
g_volume = VOLUME_DECREASE; }
}
- Once the interrupt is triggered, it first reads the value of the CLK and DT pins.
- then it compares the two: if they are the same, then a clockwise rotation has occurred, and a global volume variable is set to a value called VOLUME_INCREASE. Otherwise, a counterclockwise rotation has occurred and a global volume variable is set to a value called VOLUME_DECREASE.

Initializing the rotary encoder pins:
gpio_set_function(GPIO_VOL_DT, GPIO_FUNC_SIO); gpio_set_function(GPIO_VOL_CLK, GPIO_FUNC_SIO); gpio_set_function(GPIO_VOL_MUTE, GPIO_FUNC_SIO); gpio_set_dir(GPIO_VOL_DT, false); gpio_set_dir(GPIO_VOL_CLK, false); gpio_set_dir(GPIO_VOL_MUTE, false);

/* Set up interrupts for Rotary Encoder. */ gpio_set_irq_enabled_with_callback(GPIO_VOL_DT, GPIO_IRQ_EDGE_RISE | GPIO_IRQ_EDGE_FALL, true, gpio_vol_scroll);

- Mostly self explanatory; the gpio_set_irq_enabled_with_callback function call at the end basically creates an interrupt called gpio_vol_scroll, makes it trigger on the
GPIO_VOL_DT pin (GP10) for both falling and rising edges.

Main loop logic:
if(g_volume == VOLUME_INCREASE) { i2s_increase_volume(&i2s_config); g_volume = VOLUME_STABLE;
}
else if(g_volume == VOLUME_DECREASE) { i2s_decrease_volume(&i2s_config); g_volume = VOLUME_STABLE;
}
- Compares the global volume variable affected by the interrupt to values to call volume change functions (either to increase or decrease the volume). Then the global volume variable is set to VOLUME_STABLE to ensure only changes done by the interrupt change the volume of the system.

Analog Joystick Implementation
- The analog joystick is connected to an 8-bit precision, 8-channel ADS7830 analog to digital converter (ADC), which is connected to the Pico via I2C.
- The Analog Joystick’s xout and yout pins are connected to the ADC’s Channel 1 and Channel 0 pins, respectively.
- Used 2 GPIO pins (0 and 1) to connect to the ADC’s SDA (GP0) and SCL (GP1) pins.
- Used polling and waiting to synchronize communication between the ADC and the Pico.

ADC I2C address/commands:
#define ADS7830_ADDRESS | 0x48 | // | 1 for read

#define ADS7830_CMD_CH0 | 0x8C | // last nibble = internal ref =

on, A/D converter = on
#define ADS7830_CMD_CH1 0xCC

- The ADS7830_ADDRESS macro defines the address that all I2C communications must use to talk to the ADC.
- The ADS7830_CMD_CH0 macro defines the command that is sent to the ADC to receive the y position of the analog joystick.
- The ADS7830_CMD_CH0 macro defines the command that is sent to the ADC to receive the x position of the analog joystick.

Analog joystick global variables:
/* joystick position globals */
uint8_t g_default_x;
uint8_t g_default_y;
uint8_t g_x;
uint8_t g_y;
- There are two sets of global variables: g_default_x/y, which contains the initial power-up position of the analog joystick, and g_x/y, which contains the current position of the analog joystick.
- The “position” in any x or y direction of the joystick is just a voltage represented as a value between 0 and 255.

Initializing the ADC pins and getting the analog joystick’s initial position: gpio_set_function(GPIO_I2C0_SDA, GPIO_FUNC_I2C); gpio_set_function(GPIO_I2C0_SCL, GPIO_FUNC_I2C); gpio_pull_up(GPIO_I2C0_SDA); gpio_pull_up(GPIO_I2C0_SCL);

/* Get the default x and y coordinates of the joystick*/ const uint8_t write_ch0 = ADS7830_CMD_CH0;
const uint8_t write_ch1 = ADS7830_CMD_CH1;

i2c_init(i2c0, 400 * 1000);

uint8_t retval;
retval = i2c_write_blocking(i2c0, ADS7830_ADDRESS, &write_ch0, 1, false);
if (retval == 1) {
retval = i2c_read_blocking(i2c0, ADS7830_ADDRESS, &g_default_y, 1, false);
}

retval = i2c_write_blocking(i2c0, ADS7830_ADDRESS, &write_ch1, 1, false);
if (retval == 1) {
retval = i2c_read_blocking(i2c0, ADS7830_ADDRESS, &g_default_x, 1, false);
}
- The first 4 lines set up the GPIO pins on the Pico for I2C communication.
- The next 2 lines create variables to send via I2C that contain commands to get the x and y coordinates of the analog joystick (by instructing the ADC to send over its Channel 1 and Channel 0 voltage values as an unsigned, 8-bit integer). Note the const keyword -this is used to ensure that the commands are not changed by any of the communications.
- The next line sets the I2C peripheral used to communicate with the ADC to run at 400KHz.
- A variable, retval is used to hold the status of each I2C write/read. If retval is 1 after an i2c_read/write_blocking call, then that means that the message was read/written without issue.
- The next lines complete 4 I2C transactions:
- Write the command to the ADC to specify a read from Channel 0 of the ADC
- Read the value of Channel 0 of the ADC (and assign the read value to the default global position for y)
- Write the command to the ADC to specify a read from Channel 1 of the ADC
- Read the value of Channel 1 of the ADC (and assign the read value to the default global position for x)
- By completing these 4 I2C transactions BEFORE the main while loop, the program is able to get an initial, resting position for the joystick to use as reference when determining future joystick movements.

Main loop logic:
uint8_t b_up = gpio_get(GPIO_UP); uint8_t b_down = gpio_get(GPIO_DOWN); uint8_t b_left = gpio_get(GPIO_LEFT);
uint8_t b_right = gpio_get(GPIO_RIGHT);

retval = i2c_write_blocking(i2c0, ADS7830_ADDRESS, &write_ch0, 1, false);
if (retval == 1) {
retval = i2c_read_blocking(i2c0, ADS7830_ADDRESS, &g_y, 1, false);
}

retval = i2c_write_blocking(i2c0, ADS7830_ADDRESS, &write_ch1, 1, false);
if (retval == 1) {
retval = i2c_read_blocking(i2c0, ADS7830_ADDRESS, &g_x, 1, false);
}

//logic for joystick movement
if (g_x < (g_default_x - 50)) { //left gb.direct.joypad_bits.left = 1; gb.direct.joypad_bits.right = 0;
}
else if (g_x > (g_default_x + 50)) { //right gb.direct.joypad_bits.left = 0; gb.direct.joypad_bits.right = 1;
}
else {
gb.direct.joypad_bits.left = b_left; gb.direct.joypad_bits.right = b_right; }

if (g_y > (g_default_y + 50)) { //down gb.direct.joypad_bits.down = 0; gb.direct.joypad_bits.up = 1;
}

else if (g_y < (g_default_y - 50)) { //up gb.direct.joypad_bits.down = 1; gb.direct.joypad_bits.up = 0;
}
else {
gb.direct.joypad_bits.down = b_down; gb.direct.joypad_bits.up = b_up;
}
- The first four lines assign the button inputs to intermediary variables. These are assigned to the actual state for the up/down/left/right inputs (which are shared between the analog joystick and the buttons; the analog joystick holds priority) depending on whether the analog joystick has been moved.
- The next section with retvals is used to get the current x and y coordinates of the analog joystick by reading the Channel 1 and Channel 0 voltages of the ADC. This takes 4 I2C transactions and is the exact same as the 4 transactions in the previous section, except that the read values are put into the current x/y position variables (g_x and g_y).
- The section after the comment, “//logic for joystick movement” is the logic that determines whether the joystick has been moved from its default position - and if so, how should the up/down/left/right values be changed?
- There are two chains of if/else if/else statements to do this logic; the first is for the x position and left/right inputs, and the second is for the y position and up/down inputs.
- Each if/else if statement compares the current value for a position (g_x or g_y) to its default position (g_default_x or g_default_y) with a decent margin of error (+/-
50) to determine if the current position of the joystick constitutes as a movement. The joystick is too sensitive and inaccurate to use by comparing the default position to the current position, which is why the program uses +/- 50.
- If the joystick’s x or y position is determined to not be moved, then its respective game inputs (i.e., for x it would be left/right and for y it would be up/down) are set to the button inputs that were read in the first 4 lines.
- By doing all of this the program is able to prioritize analog joystick movements for gaming and also retain button input functionality.

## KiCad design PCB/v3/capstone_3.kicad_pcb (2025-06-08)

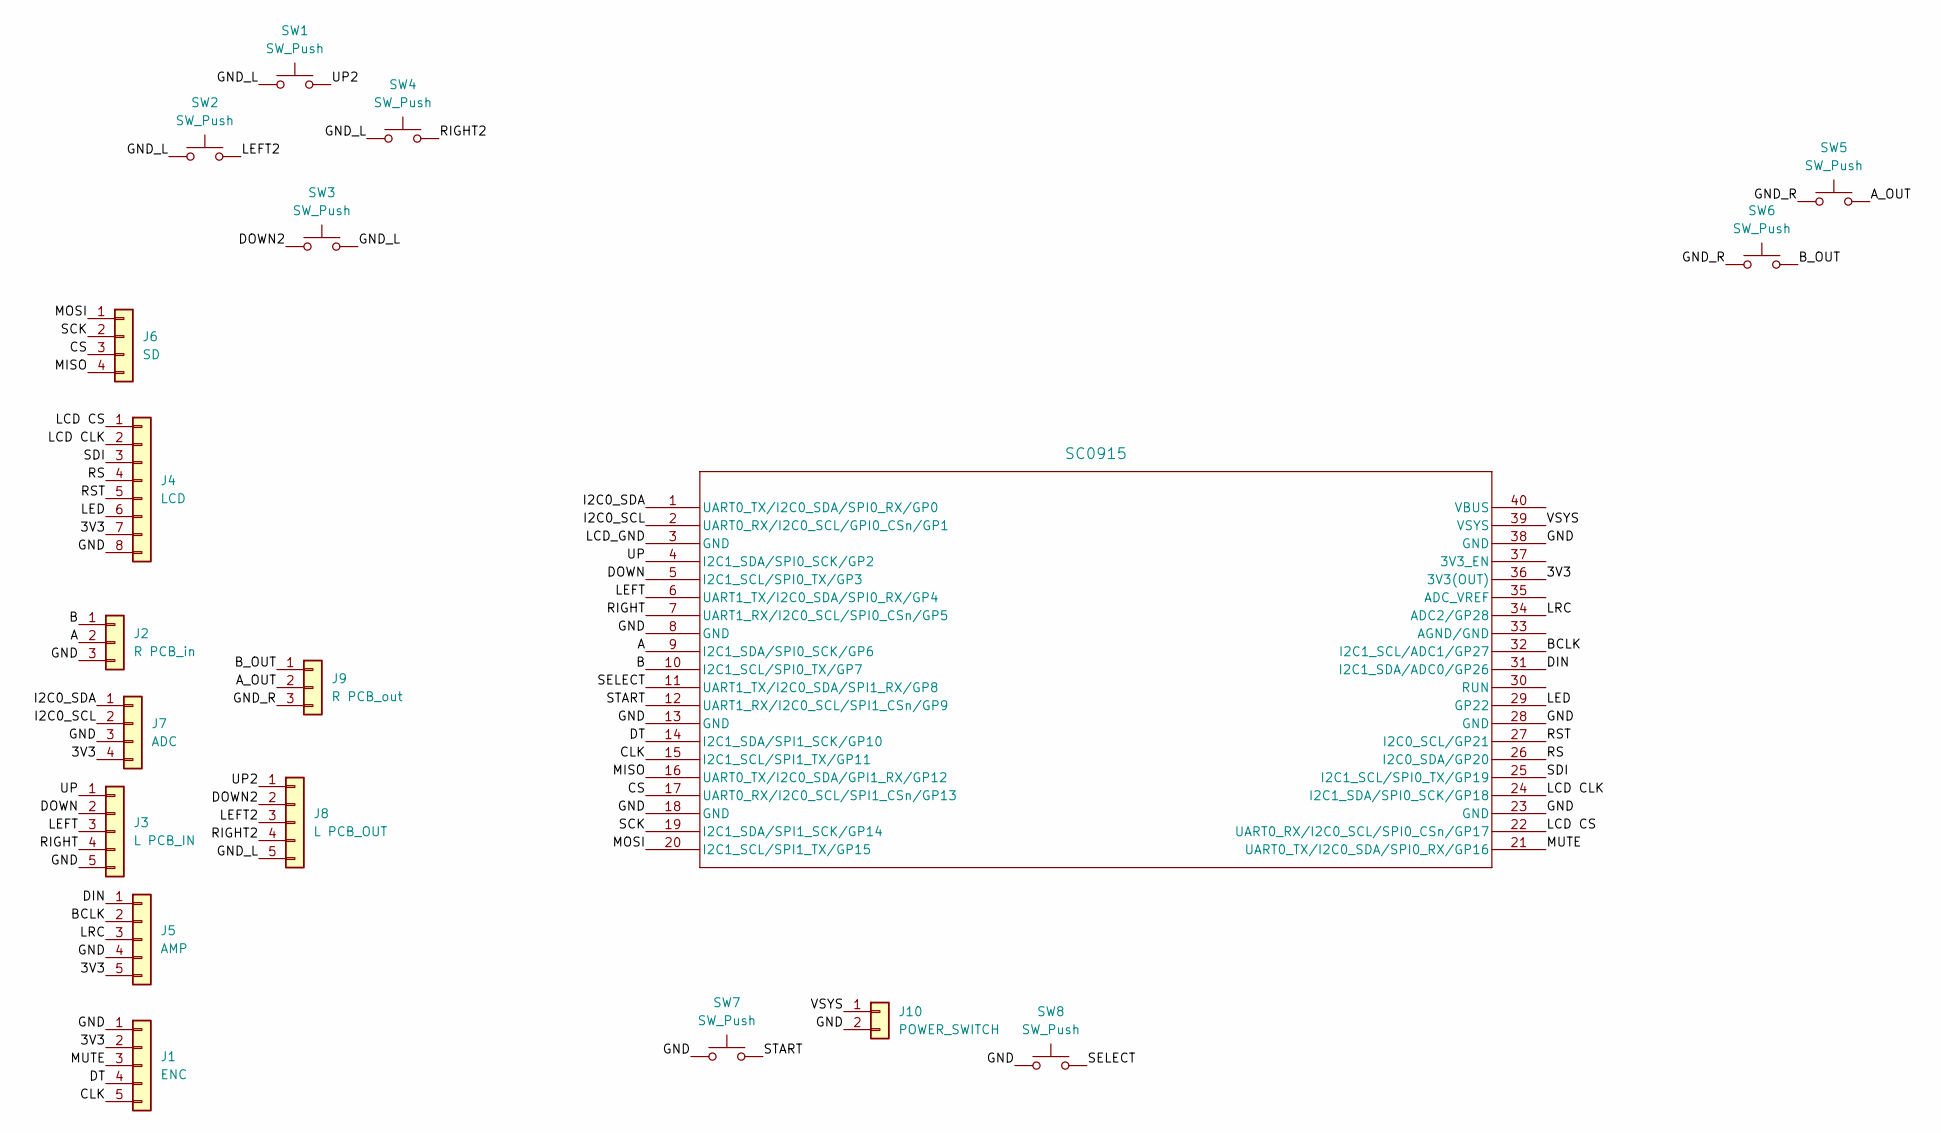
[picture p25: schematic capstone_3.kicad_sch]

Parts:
J1: ENC; PinHeader_1x05_P1.27mm_Vertical
J2: R PCB_in; PinHeader_1x03_P1.27mm_Vertical
J3: L PCB_IN; PinHeader_1x05_P1.27mm_Vertical
J4: LCD; PinHeader_1x08_P1.27mm_Vertical
J5: AMP; PinHeader_1x05_P1.27mm_Vertical
J6: SD; PinHeader_1x04_P1.27mm_Vertical
J7: ADC; PinHeader_1x04_P1.27mm_Vertical
J8: L PCB_OUT; PinHeader_1x05_P1.27mm_Vertical
J9: R PCB_out; PinHeader_1x03_P1.27mm_Vertical
J10: POWER_SWITCH; PinHeader_1x02_P2.54mm_Vertical
SW1, SW2, SW3, SW4, SW5, SW6, SW7, SW8: SW_Push; SW_PUSH_6mm
U2: SC0915; Pico THT

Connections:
/3V3: J1.2, J4.7, J5.5, J7.4, U2.36 (3V3(OUT))
/A: J2.2, U2.9 (I2C1_SDA/SPI0_SCK/GP6)
/A_OUT: J9.2, SW5.2
/B: J2.1, U2.10 (I2C1_SCL/SPI0_TX/GP7)
/BCLK: J5.2, U2.32 (I2C1_SCL/ADC1/GP27)
/B_OUT: J9.1, SW6.2
/CLK: J1.5, U2.15 (I2C1_SCL/SPI1_TX/GP11)
/CS: J6.3, U2.17 (UART0_RX/I2C0_SCL/SPI1_CSn/GP13)
/DIN: J5.1, U2.31 (I2C1_SDA/ADC0/GP26)
/DOWN: J3.2, U2.5 (I2C1_SCL/SPI0_TX/GP3)
/DOWN2: J8.2, SW3.1
/DT: J1.4, U2.14 (I2C1_SDA/SPI1_SCK/GP10)
/GND: J1.1, J2.3, J3.5, J4.8, J5.4, J7.3, J10.2, SW7.1, SW8.1, U2.8 (GND), U2.13 (GND), U2.18 (GND), U2.23 (GND), U2.28 (GND), U2.38 (GND)
/GND_L: J8.5, SW1.1, SW2.1, SW3.2, SW4.1
/GND_R: J9.3, SW5.1, SW6.1
/I2C0_SCL: J7.2, U2.2 (UART0_RX/I2C0_SCL/GPI0_CSn/GP1)
/I2C0_SDA: J7.1, U2.1 (UART0_TX/I2C0_SDA/SPI0_RX/GP0)
/LCD CLK: J4.2, U2.24 (I2C1_SDA/SPI0_SCK/GP18)
/LCD CS: J4.1, U2.22 (UART0_RX/I2C0_SCL/SPI0_CSn/GP17)
/LCD_GND: U2.3 (GND)
/LED: J4.6, U2.29 (GP22)
/LEFT: J3.3, U2.6 (UART1_TX/I2C0_SDA/SPI0_RX/GP4)
/LEFT2: J8.3, SW2.2
/LRC: J5.3, U2.34 (ADC2/GP28)
/MISO: J6.4, U2.16 (UART0_TX/I2C0_SDA/GPI1_RX/GP12)
/MOSI: J6.1, U2.20 (I2C1_SCL/SPI1_TX/GP15)
/MUTE: J1.3, U2.21 (UART0_TX/I2C0_SDA/SPI0_RX/GP16)
/RIGHT: J3.4, U2.7 (UART1_RX/I2C0_SCL/SPI0_CSn/GP5)
/RIGHT2: J8.4, SW4.2
/RS: J4.4, U2.26 (I2C0_SDA/GP20)
/RST: J4.5, U2.27 (I2C0_SCL/GP21)
/SCK: J6.2, U2.19 (I2C1_SDA/SPI1_SCK/GP14)
/SDI: J4.3, U2.25 (I2C1_SCL/SPI0_TX/GP19)
/SELECT: SW8.2, U2.11 (UART1_TX/I2C0_SDA/SPI1_RX/GP8)
/START: SW7.2, U2.12 (UART1_RX/I2C0_SCL/SPI1_CSn/GP9)
/UP: J3.1, U2.4 (I2C1_SDA/SPI0_SCK/GP2)
/UP2: J8.1, SW1.2
/VSYS: J10.1, U2.39 (VSYS)

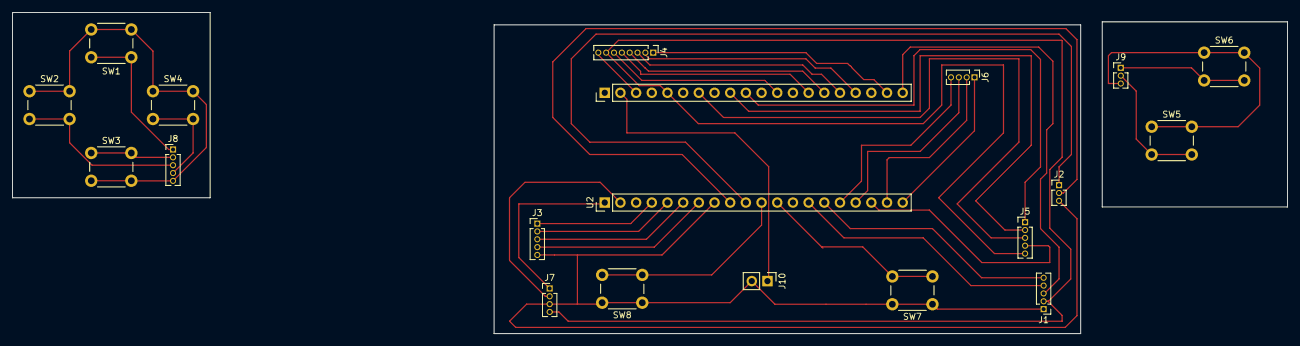
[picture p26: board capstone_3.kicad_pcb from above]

Board: 2 copper layers, 206.5 x 52.0 mm, 19 parts (0 on the bottom side), 37 nets.

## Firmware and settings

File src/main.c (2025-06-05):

/**
 * Copyright (C) 2022 by Mahyar Koshkouei <mk@deltabeard.com>
 * Modified by Gabriel Rodgers <Embedded Systems Design Club @ OSU>
 * 
 * Permission to use, copy, modify, and/or distribute this software for any
 * purpose with or without fee is hereby granted.
 * 
 * THE SOFTWARE IS PROVIDED "AS IS" AND THE AUTHOR DISCLAIMS ALL WARRANTIES WITH
 * REGARD TO THIS SOFTWARE INCLUDING ALL IMPLIED WARRANTIES OF MERCHANTABILITY
 * AND FITNESS. IN NO EVENT SHALL THE AUTHOR BE LIABLE FOR ANY SPECIAL, DIRECT,
 * INDIRECT, OR CONSEQUENTIAL DAMAGES OR ANY DAMAGES WHATSOEVER RESULTING FROM
 * LOSS OF USE, DATA OR PROFITS, WHETHER IN AN ACTION OF CONTRACT, NEGLIGENCE OR
 * OTHER TORTIOUS ACTION, ARISING OUT OF OR IN CONNECTION WITH THE USE OR
 * PERFORMANCE OF THIS SOFTWARE.
 */

// Peanut-GB emulator settings
#define ENABLE_LCD	1
#define ENABLE_SOUND	1
#define ENABLE_SDCARD	1
#define PEANUT_GB_HIGH_LCD_ACCURACY 1
#define PEANUT_GB_USE_BIOS 0

// Added settings
#define ENABLE_JOYSTICK 	0
#define ENABLE_ROTARY_ENCODER 	0

/* Use DMA for all drawing to LCD. Benefits aren't fully realised at the moment
 * due to busy loops waiting for DMA completion. */
#define USE_DMA		0

/**
 * Reducing VSYNC calculation to lower multiple.
 * When setting a clock IRQ to DMG_CLOCK_FREQ_REDUCED, count to
 * SCREEN_REFRESH_CYCLES_REDUCED to obtain the time required each VSYNC.
 * DMG_CLOCK_FREQ_REDUCED = 2^18, and SCREEN_REFRESH_CYCLES_REDUCED = 4389.
 * Currently unused.
 */
#define VSYNC_REDUCTION_FACTOR 16u
#define SCREEN_REFRESH_CYCLES_REDUCED (SCREEN_REFRESH_CYCLES/VSYNC_REDUCTION_FACTOR)
#define DMG_CLOCK_FREQ_REDUCED (DMG_CLOCK_FREQ/VSYNC_REDUCTION_FACTOR)

/* C Headers */
#include <stdio.h>
#include <stdlib.h>
#include <string.h>

/* RP2040 Headers */
#include <hardware/pio.h>
#include <hardware/clocks.h>
#include <hardware/dma.h>
#include <hardware/spi.h>
#include <hardware/sync.h>
#include <hardware/flash.h>
#include <hardware/timer.h>
#include <hardware/vreg.h>
#include <pico/bootrom.h>
#include <pico/stdio.h>
#include <pico/stdlib.h>
#include <pico/multicore.h>
#include <sys/unistd.h>
#include <hardware/irq.h>
#include <hardware/i2c.h>
#include <hardware/dma.h>

/* Project headers */
#include "hedley.h"
#include "minigb_apu.h"
#include "peanut_gb.h"
#include "mk_ili9225.h"
#include "sdcard.h"
#include "i2s.h"
#include "gbcolors.h"

/* GPIO Connections. */
#define GPIO_UP		2
#define GPIO_DOWN	3
#define GPIO_LEFT	4
#define GPIO_RIGHT	5
#define GPIO_A		6
#define GPIO_B		7
#define GPIO_SELECT	8
#define GPIO_START	9
#define GPIO_CS		17
#define GPIO_CLK	18
#define GPIO_SDA	19
#define GPIO_RS		20
#define GPIO_RST	21
#define GPIO_LED	22

/* Extended GPIO Connections. */
#if ENABLE_JOYSTICK
	#define GPIO_I2C0_SDA 	0
	#define GPIO_I2C0_SCL 	1
#endif

#if ENABLE_ROTARY_ENCODER
	#define GPIO_VOL_DT	 	10
	#define GPIO_VOL_CLK	11
	#define GPIO_VOL_MUTE	16
#endif

/* I2C addresses and commands for joystick control */
#if ENABLE_JOYSTICK
	#define ADS7830_ADDRESS     0x48    // | 1 for read
	#define ADS7830_CMD_CH0     0x8C    // last nibble = internal ref = on, A/D converter = on
	#define ADS7830_CMD_CH1     0xCC
#endif

#if ENABLE_ROTARY_ENCODER
	/* Volatile globals */
	volatile uint8_t g_volume = 0;
	volatile uint8_t g_mute = 0;

	typedef enum{
		VOLUME_INCREASE,
		VOLUME_DECREASE,
		VOLUME_STABLE
	}volume_state_t;
#endif

#if ENABLE_JOYSTICK
	/* joystick position globals */
	uint8_t g_default_x;
	uint8_t g_default_y;
	uint8_t g_x;
	uint8_t g_y;
#endif

#if ENABLE_ROTARY_ENCODER
/* Interrupts */
//interrupt for volume control
void gpio_vol_scroll(uint gpio, uint32_t event_mask) {
	uint8_t clk = gpio_get(GPIO_VOL_CLK);
	uint8_t dt = gpio_get(GPIO_VOL_DT);

	if (dt == clk) { //cw
		g_volume = VOLUME_INCREASE;
	}
	else {	 //ccw
		g_volume = VOLUME_DECREASE;
	}	
}

//interrupt for mute control - untested. 
/*
void gpio_vol_push(void_) {
	g_mute ^= 1;	//toggle g_mute
}
*/
#endif

#if ENABLE_SOUND
/**
 * Global variables for audio task
 * stream contains N=AUDIO_SAMPLES samples
 * each sample is 32 bits
 * 16 bits for the left channel + 16 bits for the right channel in stereo interleaved format)
 * This is intended to be played at AUDIO_SAMPLE_RATE Hz
 */
uint16_t *stream;
#endif

/** Definition of ROM data
 * We're going to erase and reprogram a region 1Mb from the start of the flash
 * Once done, we can access this at XIP_BASE + 1Mb.
 * Game Boy DMG ROM size ranges from 32768 bytes (e.g. Tetris) to 1,048,576 bytes (e.g. Pokemod Red)
 */
#define FLASH_TARGET_OFFSET (1024 * 1024)
const uint8_t *rom = (const uint8_t *) (XIP_BASE + FLASH_TARGET_OFFSET);
static unsigned char rom_bank0[65536];

static uint8_t ram[32768];
static int lcd_line_busy = 0;
static palette_t palette;	// Colour palette
static uint8_t manual_palette_selected=0;

static struct
{
	unsigned a	: 1;
	unsigned b	: 1;
	unsigned select	: 1;
	unsigned start	: 1;
	unsigned right	: 1;
	unsigned left	: 1;
	unsigned up	: 1;
	unsigned down	: 1;
} prev_joypad_bits;

/* Multicore command structure. */
union core_cmd {
    struct {
	/* Does nothing. */
#define CORE_CMD_NOP		0
	/* Set line "data" on the LCD. Pixel data is in pixels_buffer. */
#define CORE_CMD_LCD_LINE	1
	/* Control idle mode on the LCD. Limits colours to 2 bits. */
#define CORE_CMD_IDLE_SET	2
	/* Set a specific pixel. For debugging. */
#define CORE_CMD_SET_PIXEL	3
	uint8_t cmd;
	uint8_t unused1;
	uint8_t unused2;
	uint8_t data;
    };
    uint32_t full;
};

/* Pixel data is stored in here. */
static uint8_t pixels_buffer[LCD_WIDTH];

#define putstdio(x) write(1, x, strlen(x))

/* Functions required for communication with the ILI9225. */
void mk_ili9225_set_rst(bool state)
{
	gpio_put(GPIO_RST, state);
}

void mk_ili9225_set_rs(bool state)
{
	gpio_put(GPIO_RS, state);
}

void mk_ili9225_set_cs(bool state)
{
	gpio_put(GPIO_CS, state);
}

void mk_ili9225_set_led(bool state)
{
	gpio_put(GPIO_LED, state);
}

void mk_ili9225_spi_write16(const uint16_t *halfwords, size_t len)
{
	spi_write16_blocking(spi0, halfwords, len);
}

void mk_ili9225_delay_ms(unsigned ms)
{
	sleep_ms(ms);
}

/**
 * Returns a byte from the ROM file at the given address.
 */
uint8_t gb_rom_read(struct gb_s *gb, const uint_fast32_t addr)
{
	(void) gb;
	if(addr < sizeof(rom_bank0))
		return rom_bank0[addr];

	return rom[addr];
}

/**
 * Returns a byte from the cartridge RAM at the given address.
 */
uint8_t gb_cart_ram_read(struct gb_s *gb, const uint_fast32_t addr)
{
	(void) gb;
	return ram[addr];
}

/**
 * Writes a given byte to the cartridge RAM at the given address.
 */
void gb_cart_ram_write(struct gb_s *gb, const uint_fast32_t addr,
		       const uint8_t val)
{
	ram[addr] = val;
}

/**
 * Ignore all errors.
 */
void gb_error(struct gb_s *gb, const enum gb_error_e gb_err, const uint16_t addr)
{
#if 1
	const char* gb_err_str[4] = {
			"UNKNOWN",
			"INVALID OPCODE",
			"INVALID READ",
			"INVALID WRITE"
		};
	printf("Error %d occurred: %s at %04X\n.\n", gb_err, gb_err_str[gb_err], addr);
//	abort();
#endif
}

#if ENABLE_LCD 
void core1_lcd_draw_line(const uint_fast8_t line)
{
	static uint16_t fb[LCD_WIDTH];

	for(unsigned int x = 0; x < LCD_WIDTH; x++)
	{
		fb[x] = palette[(pixels_buffer[x] & LCD_PALETTE_ALL) >> 4]
				[pixels_buffer[x] & 3];
	}

	mk_ili9225_set_x(line + 16);
	mk_ili9225_write_pixels(fb, LCD_WIDTH);
	__atomic_store_n(&lcd_line_busy, 0, __ATOMIC_SEQ_CST);
}

_Noreturn
void main_core1(void)
{
	union core_cmd cmd;

	/* Initialise and control LCD on core 1. */
	mk_ili9225_init();

	/* Clear LCD screen. */
	mk_ili9225_fill(0x0000);

	/* Set LCD window to DMG size. */
	mk_ili9225_fill_rect(31,16,LCD_WIDTH,LCD_HEIGHT,0x0000);

	// Sleep used for debugging LCD window.
	//sleep_ms(1000);

	/* Handle commands coming from core0. */
	while(1)
	{
		cmd.full = multicore_fifo_pop_blocking();
		switch(cmd.cmd)
		{
		case CORE_CMD_LCD_LINE:
			core1_lcd_draw_line(cmd.data);
			break;

		case CORE_CMD_IDLE_SET:
			mk_ili9225_display_control(true, cmd.data);
			break;

		case CORE_CMD_NOP:
		default:
			break;
		}
	}

	HEDLEY_UNREACHABLE();
}
#endif

#if ENABLE_LCD
void lcd_draw_line(struct gb_s *gb, const uint8_t pixels[LCD_WIDTH],
		   const uint_fast8_t line)
{
	union core_cmd cmd;

	/* Wait until previous line is sent. */
	while(__atomic_load_n(&lcd_line_busy, __ATOMIC_SEQ_CST))
		tight_loop_contents();

	memcpy(pixels_buffer, pixels, LCD_WIDTH);
	
	/* Populate command. */
	cmd.cmd = CORE_CMD_LCD_LINE;
	cmd.data = line;

	__atomic_store_n(&lcd_line_busy, 1, __ATOMIC_SEQ_CST);
	multicore_fifo_push_blocking(cmd.full);
}
#endif

#if ENABLE_SDCARD
/**
 * Load a save file from the SD card
 */
void read_cart_ram_file(struct gb_s *gb) {
	char filename[16];
	uint_fast32_t save_size;
	UINT br;
	
	gb_get_rom_name(gb,filename);
	save_size=gb_get_save_size(gb);
	if(save_size>0) {
		sd_card_t *pSD=sd_get_by_num(0);
		FRESULT fr=f_mount(&pSD->fatfs,pSD->pcName,1);
		if (FR_OK!=fr) {
			printf("E f_mount error: %s (%d)\n",FRESULT_str(fr),fr);
			return;
		}

		FIL fil;
		fr=f_open(&fil,filename,FA_READ);
		if (fr==FR_OK) {
			f_read(&fil,ram,f_size(&fil),&br);
		} else {
			printf("E f_open(%s) error: %s (%d)\n",filename,FRESULT_str(fr),fr);
		}
		
		fr=f_close(&fil);
		if(fr!=FR_OK) {
			printf("E f_close error: %s (%d)\n", FRESULT_str(fr), fr);
		}
		f_unmount(pSD->pcName);
	}
	printf("I read_cart_ram_file(%s) COMPLETE (%lu bytes)\n",filename,save_size);
}

/**
 * Write a save file to the SD card
 */
void write_cart_ram_file(struct gb_s *gb) {
	char filename[16];
	uint_fast32_t save_size;
	UINT bw;
	
	gb_get_rom_name(gb,filename);
	save_size=gb_get_save_size(gb);
	if(save_size>0) {
		sd_card_t *pSD=sd_get_by_num(0);
		FRESULT fr=f_mount(&pSD->fatfs,pSD->pcName,1);
		if (FR_OK!=fr) {
			printf("E f_mount error: %s (%d)\n",FRESULT_str(fr),fr);
			return;
		}

		FIL fil;
		fr=f_open(&fil,filename,FA_CREATE_ALWAYS | FA_WRITE);
		if (fr==FR_OK) {
			f_write(&fil,ram,save_size,&bw);
		} else {
			printf("E f_open(%s) error: %s (%d)\n",filename,FRESULT_str(fr),fr);
		}
		
		fr=f_close(&fil);
		if(fr!=FR_OK) {
			printf("E f_close error: %s (%d)\n", FRESULT_str(fr), fr);
		}
		f_unmount(pSD->pcName);
	}
	printf("I write_cart_ram_file(%s) COMPLETE (%lu bytes)\n",filename,save_size);
}

/**
 * Load a .gb rom file in flash from the SD card 
 */ 
void load_cart_rom_file(char *filename) {
	UINT br;
	uint8_t buffer[FLASH_SECTOR_SIZE];
	bool mismatch=false;
	sd_card_t *pSD=sd_get_by_num(0);
	FRESULT fr=f_mount(&pSD->fatfs,pSD->pcName,1);
	if (FR_OK!=fr) {
		printf("E f_mount error: %s (%d)\n",FRESULT_str(fr),fr);
		return;
	}
	FIL fil;
	fr=f_open(&fil,filename,FA_READ);
	if (fr==FR_OK) {
		uint32_t flash_target_offset=FLASH_TARGET_OFFSET;
		for(;;) {
			f_read(&fil,buffer,sizeof buffer,&br);
			if(br==0) break; /* end of file */

			printf("I Erasing target region...\n");
			flash_range_erase(flash_target_offset,FLASH_SECTOR_SIZE);
			printf("I Programming target region...\n");
			flash_range_program(flash_target_offset,buffer,FLASH_SECTOR_SIZE);
			
			/* Read back target region and check programming */
			printf("I Done. Reading back target region...\n");
			for(uint32_t i=0;i<FLASH_SECTOR_SIZE;i++) {
				if(rom[flash_target_offset+i]!=buffer[i]) {
					mismatch=true;
				}
			}

			/* Next sector */
			flash_target_offset+=FLASH_SECTOR_SIZE;
		}
		if(mismatch) {
	        printf("I Programming successful!\n");
		} else {
			printf("E Programming failed!\n");
		}
	} else {
		printf("E f_open(%s) error: %s (%d)\n",filename,FRESULT_str(fr),fr);
	}
	
	fr=f_close(&fil);
	if(fr!=FR_OK) {
		printf("E f_close error: %s (%d)\n", FRESULT_str(fr), fr);
	}
	f_unmount(pSD->pcName);

	printf("I load_cart_rom_file(%s) COMPLETE (%lu bytes)\n",filename,br);
}

/**
 * Function used by the rom file selector to display one page of .gb rom files
 */
uint16_t rom_file_selector_display_page(char filename[22][256],uint16_t num_page) {
	sd_card_t *pSD=sd_get_by_num(0);
    DIR dj;
    FILINFO fno;
    FRESULT fr;

    fr=f_mount(&pSD->fatfs,pSD->pcName,1);
    if (FR_OK!=fr) {
        printf("E f_mount error: %s (%d)\n",FRESULT_str(fr),fr);
        return 0;
    }

	/* clear the filenames array */
	for(uint8_t ifile=0;ifile<22;ifile++) {
		strcpy(filename[ifile],"");
	}

    /* search *.gb files */
	uint16_t num_file=0;
	fr=f_findfirst(&dj, &fno, "", "*.gb");

	/* skip the first N pages */
	if(num_page>0) {
		while(num_file<num_page*22 && fr == FR_OK && fno.fname[0]) {
			num_file++;
			fr=f_findnext(&dj, &fno);
		}
	}

	/* store the filenames of this page */
	num_file=0;
    while(num_file<22 && fr == FR_OK && fno.fname[0]) {
		strcpy(filename[num_file],fno.fname);
        num_file++;
        fr=f_findnext(&dj, &fno);
    }
	f_closedir(&dj);
	f_unmount(pSD->pcName);

	/* display *.gb rom files on screen */
	mk_ili9225_fill(0x0000);
	for(uint8_t ifile=0;ifile<num_file;ifile++) {
		mk_ili9225_text(filename[ifile],0,ifile*8,0xFFFF,0x0000);
    }
	return num_file;
}

/**
 * The ROM selector displays pages of up to 22 rom files
 * allowing the user to select which rom file to start
 * Copy your *.gb rom files to the root directory of the SD card
 */
void rom_file_selector() {
    uint16_t num_page;
	char filename[22][256];
	uint16_t num_file;
	
	/* display the first page with up to 22 rom files */
	num_file=rom_file_selector_display_page(filename,num_page);

	/* select the first rom */
	uint8_t selected=0;
	mk_ili9225_text(filename[selected],0,selected*8,0xFFFF,0xF800);

	/* get user's input */
	bool up,down,left,right,a,b,select,start;
	while(true) {
		up=gpio_get(GPIO_UP);
		down=gpio_get(GPIO_DOWN);
		left=gpio_get(GPIO_LEFT);
		right=gpio_get(GPIO_RIGHT);
		a=gpio_get(GPIO_A);
		b=gpio_get(GPIO_B);
		select=gpio_get(GPIO_SELECT);
		start=gpio_get(GPIO_START);
		if(!start) {
			/* re-start the last game (no need to reprogram flash) */
			break;
		}
		if(!a | !b) {
			/* copy the rom from the SD card to flash and start the game */
			load_cart_rom_file(filename[selected]);
			break;
		}
		if(!down) {
			/* select the next rom */
			mk_ili9225_text(filename[selected],0,selected*8,0xFFFF,0x0000);
			selected++;
			if(selected>=num_file) selected=0;
			mk_ili9225_text(filename[selected],0,selected*8,0xFFFF,0xF800);
			sleep_ms(150);
		}
		if(!up) {
			/* select the previous rom */
			mk_ili9225_text(filename[selected],0,selected*8,0xFFFF,0x0000);
			if(selected==0) {
				selected=num_file-1;
			} else {
				selected--;
			}
			mk_ili9225_text(filename[selected],0,selected*8,0xFFFF,0xF800);
			sleep_ms(150);
		}
		if(!right) {
			/* select the next page */
			num_page++;
			num_file=rom_file_selector_display_page(filename,num_page);
			if(num_file==0) {
				/* no files in this page, go to the previous page */
				num_page--;
				num_file=rom_file_selector_display_page(filename,num_page);
			}
			/* select the first file */
			selected=0;
			mk_ili9225_text(filename[selected],0,selected*8,0xFFFF,0xF800);
			sleep_ms(150);
		}
		if((!left) && num_page>0) {
			/* select the previous page */
			num_page--;
			num_file=rom_file_selector_display_page(filename,num_page);
			/* select the first file */
			selected=0;
			mk_ili9225_text(filename[selected],0,selected*8,0xFFFF,0xF800);
			sleep_ms(150);
		}
		tight_loop_contents();
	}
}

#endif

int main(void)
{
	static struct gb_s gb;
	enum gb_init_error_e ret;
	
	/* Overclock. */
	{
		const unsigned vco = 1596*1000*1000;	/* 266MHz */
		const unsigned div1 = 6, div2 = 1;

		vreg_set_voltage(VREG_VOLTAGE_1_15);
		sleep_ms(2);
		set_sys_clock_pll(vco, div1, div2);
		sleep_ms(2);
	}

	/* Initialise USB serial connection for debugging. */
	stdio_init_all();
	time_init();
	// sleep_ms(5000);
	putstdio("INIT: ");

	/* Initialise GPIO pins. */
	gpio_set_function(GPIO_UP, GPIO_FUNC_SIO);
	gpio_set_function(GPIO_DOWN, GPIO_FUNC_SIO);
	gpio_set_function(GPIO_LEFT, GPIO_FUNC_SIO);
	gpio_set_function(GPIO_RIGHT, GPIO_FUNC_SIO);
	gpio_set_function(GPIO_A, GPIO_FUNC_SIO);
	gpio_set_function(GPIO_B, GPIO_FUNC_SIO);
	gpio_set_function(GPIO_SELECT, GPIO_FUNC_SIO);
	gpio_set_function(GPIO_START, GPIO_FUNC_SIO);
	gpio_set_function(GPIO_CS, GPIO_FUNC_SIO);
	gpio_set_function(GPIO_CLK, GPIO_FUNC_SPI);
	gpio_set_function(GPIO_SDA, GPIO_FUNC_SPI);
	gpio_set_function(GPIO_RS, GPIO_FUNC_SIO);
	gpio_set_function(GPIO_RST, GPIO_FUNC_SIO);
	gpio_set_function(GPIO_LED, GPIO_FUNC_SIO);
	
	gpio_set_dir(GPIO_UP, false);
	gpio_set_dir(GPIO_DOWN, false);
	gpio_set_dir(GPIO_LEFT, false);
	gpio_set_dir(GPIO_RIGHT, false);
	gpio_set_dir(GPIO_A, false);
	gpio_set_dir(GPIO_B, false);
	gpio_set_dir(GPIO_SELECT, false);
	gpio_set_dir(GPIO_START, false);
	gpio_set_dir(GPIO_CS, true);
	gpio_set_dir(GPIO_RS, true);
	gpio_set_dir(GPIO_RST, true);
	gpio_set_dir(GPIO_LED, true);
	gpio_set_slew_rate(GPIO_CLK, GPIO_SLEW_RATE_FAST);
	gpio_set_slew_rate(GPIO_SDA, GPIO_SLEW_RATE_FAST);

	gpio_pull_up(GPIO_UP);
	gpio_pull_up(GPIO_DOWN);
	gpio_pull_up(GPIO_LEFT);
	gpio_pull_up(GPIO_RIGHT);
	gpio_pull_up(GPIO_A);
	gpio_pull_up(GPIO_B);
	gpio_pull_up(GPIO_SELECT);
	gpio_pull_up(GPIO_START);

	/* Set SPI clock to use high frequency. */
	clock_configure(clk_peri, 0,
		CLOCKS_CLK_PERI_CTRL_AUXSRC_VALUE_CLK_SYS,
		125 * 1000 * 1000, 125 * 1000 * 1000);
	spi_init(spi0, 30*1000*1000);
	spi_set_format(spi0, 16, SPI_CPOL_0, SPI_CPHA_0, SPI_MSB_FIRST);

#if ENABLE_ROTARY_ENCODER
	gpio_set_function(GPIO_VOL_DT, GPIO_FUNC_SIO);
	gpio_set_function(GPIO_VOL_CLK, GPIO_FUNC_SIO);
	gpio_set_function(GPIO_VOL_MUTE, GPIO_FUNC_SIO);
	gpio_set_dir(GPIO_VOL_DT, false);  
	gpio_set_dir(GPIO_VOL_CLK, false);
	gpio_set_dir(GPIO_VOL_MUTE, false);

	/* Set up interrupts for Rotary Encoder. */
	gpio_set_irq_enabled_with_callback(GPIO_VOL_DT, GPIO_IRQ_EDGE_RISE | GPIO_IRQ_EDGE_FALL, true, gpio_vol_scroll);
#endif

#if ENABLE_JOYSTICK
	gpio_set_function(GPIO_I2C0_SDA, GPIO_FUNC_I2C);
	gpio_set_function(GPIO_I2C0_SCL, GPIO_FUNC_I2C);
	gpio_pull_up(GPIO_I2C0_SDA);
	gpio_pull_up(GPIO_I2C0_SCL);

	/* Get the default x and y coordinates of the joystick*/
    const uint8_t write_ch0 = ADS7830_CMD_CH0;
	const uint8_t write_ch1 = ADS7830_CMD_CH1;

	i2c_init(i2c0, 400 * 1000);

	uint8_t retval; 
	retval = i2c_write_blocking(i2c0, ADS7830_ADDRESS, &write_ch0, 1, false);
	if (retval == 1) {
		retval = i2c_read_blocking(i2c0, ADS7830_ADDRESS, &g_default_y, 1, false);
	}

	retval = i2c_write_blocking(i2c0, ADS7830_ADDRESS, &write_ch1, 1, false);
	if (retval == 1) {
		retval = i2c_read_blocking(i2c0, ADS7830_ADDRESS, &g_default_x, 1, false);
	}
#endif

#if ENABLE_SOUND
	// Allocate memory for the stream buffer
	stream=malloc(AUDIO_BUFFER_SIZE_BYTES);
    assert(stream!=NULL);
    memset(stream,0,AUDIO_BUFFER_SIZE_BYTES);  // Zero out the stream buffer
	
	// Initialize I2S sound driver
	i2s_config_t i2s_config = i2s_get_default_config();
	i2s_config.sample_freq=AUDIO_SAMPLE_RATE;
	i2s_config.dma_trans_count =AUDIO_SAMPLES;
	i2s_volume(&i2s_config,2);
	i2s_init(&i2s_config);
#endif

//-----------------------------------------------------------------------------//
while(true)
{
#if ENABLE_LCD
#if ENABLE_SDCARD
	/* ROM File selector */
	mk_ili9225_init();
	mk_ili9225_fill(0x0000);
	rom_file_selector();
#endif
#endif

	/* Initialise GB context. */
	memcpy(rom_bank0, rom, sizeof(rom_bank0));
	ret = gb_init(&gb, &gb_rom_read, &gb_cart_ram_read,
		      &gb_cart_ram_write, &gb_error, NULL);
	putstdio("GB ");

	if(ret != GB_INIT_NO_ERROR)
	{
		printf("Error: %d\n", ret);
		goto out;
	}

	/* Automatically assign a colour palette to the game */
	char rom_title[16];
	auto_assign_palette(palette, gb_colour_hash(&gb),gb_get_rom_name(&gb,rom_title));
	
#if ENABLE_LCD
	gb_init_lcd(&gb, &lcd_draw_line);

	/* Start Core1, which processes requests to the LCD. */
	putstdio("CORE1 ");
	multicore_launch_core1(main_core1);
	
	putstdio("LCD ");
#endif

#if ENABLE_SOUND
	// Initialize audio emulation
	audio_init();
	
	putstdio("AUDIO ");
#endif

#if ENABLE_SDCARD
	/* Load Save File. */
	read_cart_ram_file(&gb);
#endif

	putstdio("\n> ");
	uint_fast32_t frames = 0;
	uint64_t start_time = time_us_64();
	while(1)
	{
		int input;

		gb.gb_frame = 0;

		do {
			__gb_step_cpu(&gb);
			tight_loop_contents();
		} while(HEDLEY_LIKELY(gb.gb_frame == 0));

		frames++;
#if ENABLE_SOUND
		if(!gb.direct.frame_skip) {
			audio_callback(NULL, stream, AUDIO_BUFFER_SIZE_BYTES);
			i2s_dma_write(&i2s_config, stream);
		}
#endif

		/* Update buttons state */
		prev_joypad_bits.up=gb.direct.joypad_bits.up;
		prev_joypad_bits.down=gb.direct.joypad_bits.down;
		prev_joypad_bits.left=gb.direct.joypad_bits.left;
		prev_joypad_bits.right=gb.direct.joypad_bits.right;
		prev_joypad_bits.a=gb.direct.joypad_bits.a;
		prev_joypad_bits.b=gb.direct.joypad_bits.b;
		prev_joypad_bits.select=gb.direct.joypad_bits.select;
		prev_joypad_bits.start=gb.direct.joypad_bits.start;
#if (ENABLE_JOYSTICK == 0)
		gb.direct.joypad_bits.up=gpio_get(GPIO_UP);
		gb.direct.joypad_bits.down=gpio_get(GPIO_DOWN);
		gb.direct.joypad_bits.left=gpio_get(GPIO_LEFT);
		gb.direct.joypad_bits.right=gpio_get(GPIO_RIGHT);
#endif
		gb.direct.joypad_bits.a=gpio_get(GPIO_A);
		gb.direct.joypad_bits.b=gpio_get(GPIO_B);
		gb.direct.joypad_bits.select=gpio_get(GPIO_SELECT);
		gb.direct.joypad_bits.start=gpio_get(GPIO_START);
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

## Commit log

2025-03-19 added functionality to toggle on-board LED.
2025-03-20 started rotary encoder stuff
2025-04-08 starting adding I2C stuff
2025-04-09 continuing the i2c grind
2025-06-02 working both versions - with and without rotary encoder/analog joystick
2025-06-07 still need to add pcb
    [Battery_covers.stl, Batterycover.stp, Bottom_shell.stl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]
